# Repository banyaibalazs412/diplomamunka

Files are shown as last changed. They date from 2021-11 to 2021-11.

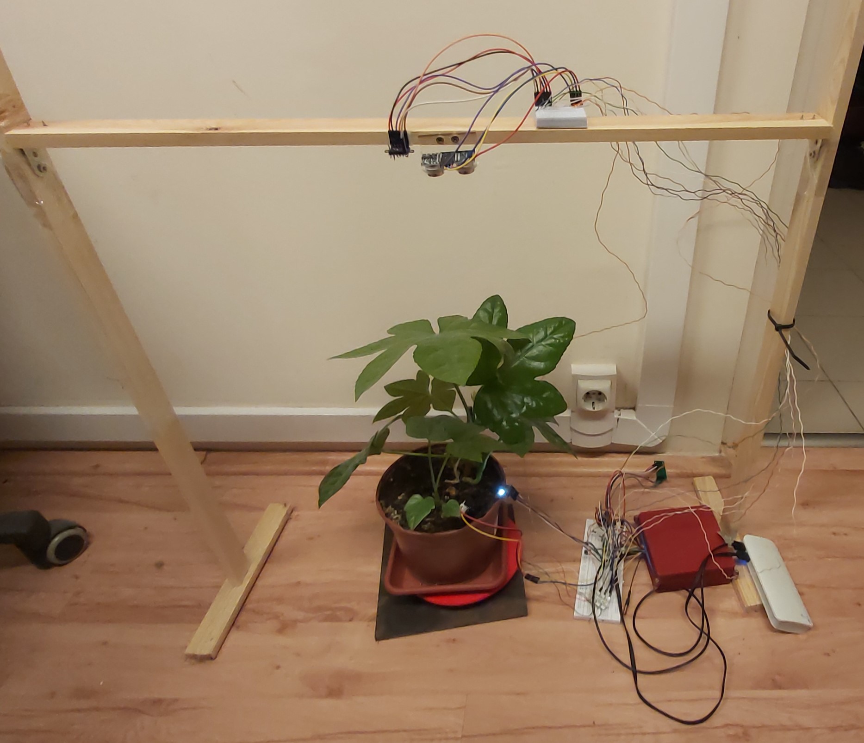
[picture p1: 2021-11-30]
abrak_egyeb/20211123_200445.jpg

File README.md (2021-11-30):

# Bányai Balázs - Diplomamunka 2021

Az állományok:

diplomamunka_frontend -> Weboldal,
ESP_code -> ESP32 mikrovezélrő Arduino kód,
greenHouseMonitoring -> ARM Cortex M alapú mikrovezérlő (STM32L452RE-P) kód,
node_api -> ExpressJs Server oldali API,
abrak_egyeb -> Minden a diplomamunkához tartozó ábra, 3D nyomtatáshoz szükséges fileok...

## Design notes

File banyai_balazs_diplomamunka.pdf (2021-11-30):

## Szegedi Tudományegyetem

## Informatikai Intézet

# DIPLOMAMUNKA

# Bányai Balázs

2021

## Szegedi Tudományegyetem Informatikai Intézet

## Növény monitorozó rendszer üvegházi alkalmazásokra

## Diplomamunka

Készítette: | Témavezető:
Bányai Balázs | Dr. Mingesz Róbert
| Zoltán
Mérnökinformatika szakos hallgató | egyetemi adjunktus

## Szeged

2021

Növény monitorozó rendszer üvegházi alkalmazásokra

Feladatkiírás

Manapság egyre nagyobb hangsúly kerül a termelési hatékonyság növelésére. Nincs ez

másképpen a növények termesztésénél sem. A hatékonyság növelésének egy módja lehet

az, hogy a növényeket és környezetüket folyamatosan megfigyeljük és adatokat gyűjtünk

be. Az adatok alapvetően jelentős információkat tartalmaznak, de a hatékonyság nagy

mértékű növelése érdekében érdemes az adatok változását valamiféle beavatkozás

eredményeként tekinteni. A fent leírtak alapján a munka célja egy olyan rendszer

kifejlesztése, ami folyamatosan monitorozza a növényeket és környezetüket üvegházi

környezetben. Az adatokat adatbázisban tárolja, és a végfelhasználónak értelmezhető

módon megjeleníti egy weboldal segítségével. Az adatok mérését és továbbítását

mikrovezérlők végzik. A mikrovezérlők az üvegházi környezet miatt vezetéknélküli

kommunikációval továbbítják az adatot. A megvalósításhoz felhasználható eszközök:

ARM Cortex M és ESP32 mikrovezérlő, adatbázis, webes keretrendszerek.

A munka során a következő alapvető funkciók megvalósítása szükséges:

- Weboldal készítése, ahol a felhasználó áttekintheti a mért adatokat.
- Felhasználói szintek kezelése (csak olvasás, paraméterek írása)
- API készítése az adatok feldolgozására
- Adatok adatbázisban való tárolása
- Növények és környezet monitorozása, adatok továbbítása
- Berendezés védelme a környezeti hatásokkal szemben.

Tartalmi összefoglaló

A téma megnevezése:

Növény monitorozó rendszer üvegházi alkalmazásokra.

A megadott feladat megfogalmazása:

A feladat egy növény monitorozó rendszer megvalósítása. A rendszer több részből áll.

Egyik része képes a növény és a környezet különböző fizikai tulajdonságait mérni. A

másik része fogadja az adatot, eltárolja, majd meg is jeleníti azt egy végfelhasználó

számára egyszerűen kezelhető weboldal segítségével.

A megoldási mód:

A feladat megoldásához szükségem volt egy teszt környezetre. Mivel a növény

magasságát vertikálisan mértem, így szükség volt egy állványra, aminek segítségével a

mérést meg tudtam valósítani. Ezen felül kellet egy növény, amin a méréseket végre

tudtam hajtani. Az jelenlegi időszakra való tekintettel egy szobanövényt választottam.

Alkalmazott eszközök, módszerek:

A rendszer magvalósításához szükségem volt két mikrovezérlőre, továbbá a méréshez

nélkülözhetetlen szenzorokra. Az adatok tárolására a MongoDB felhő alapú szolgáltatását

választottam. Az adatok feldolgozását és megjelenítését JavaScript keretrendszerek

biztosítják.

Elért eredmények:

A Feladat kiírásban szereplő követelményeket sikerült megvalósítanom. A növény

monitorozó rendszert teszteltem az általam megalkotott teszt környezetben. A feladat

során egy olyan rendszert sikerült megvalósítani, ami valós üvegházi környezetben is

megállná a helyét.

Kulcsszavak:

növény monitorozás, mikrovezérlő, VueJS, NodeJS, MongoDB, Szenzorok

Tartalomjegyzék

Bevezetés

Napjainkban egyre nagyobb hangsúlyt fektetünk arra, hogy minél hatékonyabban és

minél kevesebb pazarlással végezzük a termelést. Annak érdekében, hogy a hatékonysági

fokot növeljük, méréseket kell végezzünk, hogy legyen viszonyítási alapunk. A

diplomamunkám kifejezetten a növények üvegházi környezetben való termesztésére

összpontosít.

Két nagyobb területen is alkalmazható az általam elkészített monitorozó rendszer.

Az egyik ilyen terület a nagy mennyiségben való termesztés, ahol az elsődleges cél a

termés mennyiségének maximalizálása. Erre az alkalmazásra hasznosnak bizonyulhat

egy rendszer, ahol figyelemmel lehet követni a növény és a környezet különböző

tulajdonságait. A másik alkalmazása pedig a genetikailag módosított növények figyelése.

A közeljövőben a klíma változás hatására nagy szerepet fog kapni a genetikailag

módosított növények előállítása. Az általunk még nem ismert növények minden

változását figyelemmel szeretnénk követni annak érdekében, hogy meg tudjuk mondani

a genetikai módosítások sikerességét.

### 1. Adatbázis és szerver oldali technológiák

Az adatok tárolására a választásom a MongoDB-re esett. Az adatbázissal való

kommunikációt pedig egy NodeJS keretrendszer segítségével valósítottam meg.

Bármilyen tárolt adat lekérdezése vagy módosítása csak ezen a NodeJS

alkalmazásprogramozási felületen (későbbiekben: API) keresztül történhet meg a

rendszerben, leszámítva a direkt adatbázis műveleteket.

### 1.1 MongoDB

A MongoDB egy nyílt forráskódú dokumentum adatbázis. A dokumentum adatbázisokat

nem relációs, vagy más néven NoSQL adatbázisoknak is szokás nevezni. Ennek előnye

az, hogy nem adat táblákban kell tároljuk az adatokat egy előre megadott modell alapján,

így sokkal rugalmasabb adat struktúrákat tudunk benne letárolni. Emellett nem szükséges

az összes adatnak rendelkeznie ugyan azokkal az adat tagokkal. A MongoDB

széleskörűen elterjed a programozók körében, mivel használata nagyon egyszerű, sokkal

kevesebb megkötéssel rendelkezik, mint egy relációs adatbázis. Az adatbázis tervezési

fázisban töltött idő nagy mértékben rövidülhet. Ez főleg azért lehetséges, mert ahogy azt

már említettem, az adatbázis táblák nem egy kötött struktúrát követnek. Továbbá nem

szükséges adatbázis normalizálási lépéseket végeznünk. A NoSQL adatbázisok egyik

nagy előnye, hogy nagy mennyiségű adat tárolására is képesek drasztikus sebesség

csökkenés nélkül. Amiatt, hogy nincs szükség több tábla összefűzésére, a lekérdezéseink

is gyorsabban végre hajtódnak, mint egy relációs adatbázisban. Az én rendszeremben

nagyon sok mérési adat keletkezhet, ezért döntöttem úgy, hogy ezt az adatbázist fogom

használni. [1, 2, 3, 4]

A MongoDB a relációs adatbázisoktól eltérően dokumentumok tárolására képes.

A dokumentumok JSON alapúak, ami egy széleskörűen elterjedt adat formátum. A JSON

a JavaScript Object Notation angol kifejezés mozaik szava. Szöveges alapú,

programozási nyelv független és emberi szemmel is könnyen értelmezhető. A kis, de jól

definiált szabályai miatt könnyen kezelhető. A relációs adatbázisoktól eltérően itt nem

táblák, hanem úgynevezett collectionok (gyűjtemények) vannak, amelyek tárolják a

logikailag összefüggő dokumentumokat. [5]

### 1.2 MongoDB Atlas

A MongoDB Atlas egy felhő szolgáltatás, amit a MongoDB kínál. Az egyik nagy előnye,

hogy nincs szükség egy külön szerver gépet fent tartanunk annak érdekében, hogy a

növény monitorozó rendszerünk adatbázisa folyamatosan elérhető legyen. Ahogy az

minden felhő szolgáltatásra jellemző, ebben az esetben is egy skálázható szolgáltatást

kapunk. Csak annyi erőforrást használ az adatbázis, amennyire az adott pillanatban

szüksége van. Ha növeljük az adatok mennyiségét, vagy esetleg az adat forgalmat, akkor

a felhő szolgáltató számunkra nem észrevehető módon bővíti a felhasználható

erőforrásokat. Az Atlas folyamatos backup mentéseket hajt végre időközönként annak

érdekében, hogy az adataink ne vesszenek el valamiféle meghibásodás következtében. Az

adatbázis elérése szempontjából is előnyös lehet számunkra a felhő szolgáltatás, mivel a

világ teljes területén biztosítanak szervert számunkra. A MongoDB Atlas önmagában

nem nyújt felhő szolgáltatást, de a legnagyobb felhő szolgáltató cégekkel együtt működve

több szolgáltatón keresztül is lehetséges a szolgáltatás igénybevétele. Igénybe vehetjük

az Amazon Web Service (AWS), Microsoft Azure vagy akár a Google Cloud Platform

szolgáltatásait is. Sőt, lehetőségünk van akár több szolgáltatást is használni egyszerre. A

diplomamunkámban az AWS szolgáltatás választottam, mivel régionként különböző

árazással rendelkeznek és esetemben bizonyos korlátokig ez az opció ingyenesen

használható. A rendszer bővülésével, mind az adat mennyiség, mind a területi eloszlást

figyelembe véve érdemes lehet megvizsgálni, hogy melyik szolgáltatás a legelőnyösebb

számunkra. A szolgáltatók sok esetben más mennyiségek szerint készítik az árszabásukat.

Valahol az adat mennyisége, valahol a szerverrel való kommunikációk számát mérik, de

további mérőszámokat is alkalmaznak. A MongoDB Atlas online kezelőfelületén

lehetőségünk van figyelni, hogy az adatbázisunkhoz az elmúlt időben hányan

csatlakoztak és mekkora adatforgalmat generáltak. Az adatforgalom kijelzésénél külön

választva nézhetjük az írt és olvasott adat mennyiségeket is. [6, 7]

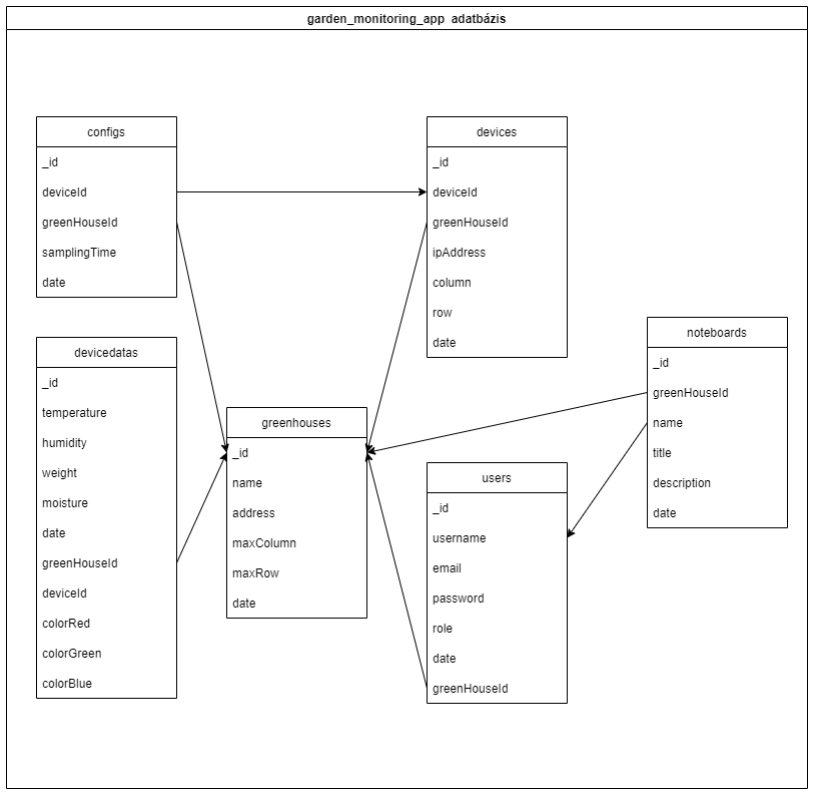
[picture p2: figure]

1.2 1. ábra Adatbázis felépítése

### 1.3 NodeJS

A NodeJS egy JavaScript runtime ami alapvetően aszinkron működésre lett tervezve

szerver oldalon. Olyan alkalmazásoknál, ahol szerver oldalon nem szükséges nagy

számításokat végezni, előszeretettel használják egyszerűsége és gyorsasága miatt. A

fejlesztőknek nem kell foglalkozniuk a szálkezeléssel, mivel a kérések nem blokkolják

egymást. A másik nagy előnye, hogy egyszerűen összekapcsolható MongoDB

adatbázisokkal. Az egyik legnagyobb hátránya, hogy relációs adatbázisokkal viszont

nehezebben összekapcsolható, mivel a kapcsolódáshoz tartozó függvény könyvtárak

fejlesztése lassabban halad, mivel a felhasználói igény sem túl nagy ezeknek a

fejlesztésére. A NodeJS által használható függvénycsomagok telepítése egy úgynevezett

package manager-en keresztül történik, aminek a neve Node Package Manager (npm). A

package managerre úgy is tekinthetünk, mint egy nyílt közösségi függvénycsomag

tárhely. [8, 9]

### 1.4 Express JS

Az Express JS egy ingyenes, nyílt forráskódú NodeJS keretrendszer, aminek segítségével

gyorsan és egyszerűen tudunk JavaScript alapú szerver oldali alkalmazásokat fejleszteni.

A növény monitorozó rendszer esetében ezt a keretrendszert használtam arra, hogy

készítsek egy olyan szerver oldali JavaScript API-t, ami HTTP protokollon keresztül

hívható, és feladata az adatbázis és a weboldal/mikrovezérlő közti kommunikáció

megteremtése. Mivel az adatokat kis mértékben módosítjuk, és vannak olyan végpontok,

amik nem csak adatbázisban való módosításra hivatottak így szükségünk volt egy köztes

rétegre és ez a köztes réteg az Express API. [10, 11]

### 1.5 Szerver oldali Express alkalmazás létrehozása

Első lépésként az eszközünkre telepítenünk kell a már előbbiekben említett NPM package

manager-t, majd a NodeJS-t. A projekt létrehozását könnyen meg tehetjük Windows

operációs rendszeren egy Windows Power Shell vagy egy Command promt segítségével.

Linux vagy MacOS operációs rendszernél pedig egy terminál segítségével. Az npm init

parancs kiadásával létrehozzuk a projektünk alap tulajdonságait leíró package.json file-t.

A parancs kiadása után meg tudunk adni olyan tulajdonságokat, hogy mi a projekt neve,

ki a szerző, mi a készülendő projekt verzió száma, rövid leírása, belépési pontja és még

sok más a projektet leíró tulajdonságot.

A package.json file a későbbiekben nem csak a projekt alapvető szöveges

tulajdonságait fogja leírni, de itt fogja tárolni a projektben használt függőségek listáját is.

Ha a projektet meg szeretnénk osztani másokkal, esetleg valamilyen verziókezelőt

használunk, akkor fontos, hogy ezt a file-t mindenképpen mellékeljük. Bevett szokás,

hogy a node_modules könyvtárat, ahol a valós függvénycsomagok tarolódnak nem

osztjuk meg, mivel sok kis méretű állományt tartalmaznak, amely elérhető az NPM

package manager segítségével, így feleslegesen terhelnénk a tárhelyet. Emellett a

függőségek listájában a szükséges csomagok verziószáma is el van tárolva, ezzel

biztosítva azt, hogy másik eszközön való üzembe helyezés során ne lépjenek fel

verziószám különbség által keletkező problémák. Másik eszközön való beüzemeléshez

elegendő belépnünk abba a könyvtárba, ahol a package.json file található és

parancssorból ki kell adjuk az npm install parancsot.

Az Express JS keretrendszer telepítése sem különbözik a többi függvénycsomag

telepítésétől. A csomagok telepítése a következő paranccsal történik npm install

<függvénycsomag neve><@verziószám>. A „@” jel és a verzió szám megadása

opcionális. Abban az esetben, ha ezt nem adjuk meg, akkor a legfrisseb elérhető verzió

kerül telepítése. Ezen felül van lehetőségünk a csomag telepítésére lokálisan a projekthez

és globális a számítógépünkre. Alapvetően a projekthez fogja telepíteni, de a -g kapcsoló

megadásával az eszközünkre is tudjuk telepíteni. Ez akkor lehet előnyös, ha több

projekten is dolgozunk, ami ugyan azokat a csomagokat használják és ugyan azon

verziószámmal. Ezek alapján az Express JS telepítése a projektünkhöz az npm install

express paranccsal történik.

### 2. A rendszerhez tartozó Express API

Elsőnek létre kell hozzuk az package.json-ben megadott belépési pontot, ami esetemben

az index.js file. Mielőtt elkezdnénk a fejlesztést érdemes hozzá adnunk a projektünkhöz

egy csomagot, aminek az a neve, hogy nodemon. Ez a csomag fejlesztés alatt segít majd

minket. A nodemon lényege az, hogy nem kell minden változtatásnál újra indítanunk az

alkalmazást, mert minden file változás esetén ő ezt automatikusan elvégzi, ami nagyban

gyorsítja a fejlesztési folyamatot.

Az express keretrendszer használatához jeleznünk kell, hogy használni fogjuk az

express csomagot. A használathoz a require() függvényt kell használnunk, a dolgunk csak

annyi, hogy a függvény paraméterében String formában meg kell adjuk a használni kívánt

csomag nevét. Az express esetén szükségünk van egy példány létrehozására is, amit a

későbbiekben használni fogunk.

2. 1. ábra Express példány létrehozása

Ez után tudjuk használni az app példány függvényeit. Ahhoz, hogy elérjük az API-t be

kell állítsunk egy portot, amit figyel és itt fogja várni a HTTP kéréseket. Ezt az

app.listen() függvény segítségével tehetjük meg. A függvény egy Number típusú

paramétert vár, ami az általunk megadott portot fogja jelenteni. Esetemben ez a 3000-es port lesz, de bármilyen nyitott port megadása lehetséges. Ezután az alkalmazásunkat az

npm start parancs kiadásával tudjuk futtatni a nodemon miatt, és futása alatt végig figyeli

a 3000-es porton érkező kéréseket.

### 2.1 Mongoose

Miután már van egy futó alkalmazásunk, létre kell hozzuk a kapcsolatot az

adatbázisunkkal. A kapcsolat létrehozáshoz és minden adatbázis művelethez a mongoose

csomagot használtam, amely kifejezetten a MongoDB és a NodeJS alkalmazások

összekötésére lett kitalálva. Használata nagyon egyszerű és a csomag nagyon jól

dokumentált.

Használatához hasonló módon a require() függvényt kell használnunk. Az

adatbázishoz való csatlakozáshoz a mongoose.connect() függvényt tudjuk használni,

amelynek az első paramétere az adatbázis elérési útja. Ezt könnyen meg tudjuk nézni a

MongoDB Atlas kezelőfelületén. Lehetőségünk van kiválasztani, hogy milyen

programozási nyelven készítjük az alkalmazást, és miután ezt meg tettük, meg kapjuk az

elérési utat, sőt még egy rövid példa kódot is a beüzemeléséhez. A mongoose.connect()

függvénynek van egy második opcionális paramétere amellyel egyéb adatbázis

kapcsolathoz köthető beállításokat lehet megadni. Ezen opciók listája megtalálható a

mongoose dokumentációjában. A monitorozó rendszerben nem használok az adatbázis

elérési úton kívül semmilyen egyéb beállítást.

A mongoose segítségével létre tudunk hozni adat sémákat, amelyben meg tudjuk

adni, hogy a dokumentumok milyen attribútumokkal fognak rendelkezni. Az

attribútumokhoz meg tudjuk adni a nevüket, hogy milyen típusúak (csak JavaScript

beépített típusok), hogy kötelezően meg kell-e adjuk és ha szükséges, akkor egy alap

értéket is. Továbbá a séma második paramétereként egy verzió kulcs is megadható, de én

ezt az opciót nem használom. Az így definiált sémából létre tudunk hozni egy úgynevezett

mongoose modelt. A mongoose model létrehozásához szükségünk van egy collection

névre és az előbbiekben leírt mongoose sémára.

### 2.2 Jogosultsági körök

Az egész monitorozó rendszerben három féle jogosultsági kört különböztetünk meg. Ezek

szükség esetén a későbbiekben könnyen bővíthetőek. Az egyik jogosultsági kör a „User”, aki egy sima felhasználó. A User képes lekérdezni monitorozási adatot a hozzá rendelt

üvegházból, de beavatkozni sehova se tud. A második jogosultsági kör az „Admin”, aki

egy üvegház vezetőjének felel meg. Lehetősége van az üvegházhoz tartozó monitorozási

adatok lekérdezésére. Ezen felül kezdeményezhet egy azonnali mérést az üvegházhoz

rendelt mikrovezérlőn. Továbbá lehetősége van az üvegház adatainak módosításához,

vehet fel új eszközöket a saját üvegházhoz, módosíthatja a meglévő eszközök

konfigurációját és kezelheti az üvegházhoz rendelt felhasználókat. Az utolsó jogosultsági

kör a „SuperAdmin”. Valójában ez egy rendszer üzemeltető jogkör. A monitorozási

adatokhoz nem fér hozzá. Szerepe, hogy új üvegházakat vegyen fel és az üvegházakhoz

Adminokat rendeljen.

### 2.3 JWT

A JWT az angol JSON Web Token kifejezésből ered. Szerepe a biztonság növelése,

emellett használható a felhasználók azonosítására is. Az express alkalmazásban a

jsonwebtoken csomag segítségével tudjuk használni. A bejelentkezési fázisnál az

alkalmazás generál egy JWT tokent, amely bizonyos végpontok hívásánál

nélkülözhetetlen. Ha ezeket a végpontokat JWT nélkül szeretnénk hívni, akkor hiba

üzenetet kapunk válaszul a kérésünkre. A JWT generáláshoz HS256 titkosítási

algoritmust használ, ami egy szimmetrikus titkosítás. A kulcs generáláshoz szükségünk

van egy úgynevezett secretre. Az alkalmazásomban erre létre hoztam egy külön config.js

file-t, amiben ezt könnyedén tudjuk változtatni.

2.3 1. ábra JWT token generálása

Az ábrán látszik, hogy a jsonwebtoken csomag sign() függvény segítségével tudunk

tokent generálni. Három paramétert vár, az első a felhasználó azonosítója, a második az előbbiekben említett secret és a harmadik paraméterben több beállítás is megadható. Én

egyedül a lejárati időt adtam meg, ami jelenleg 24 óra. A token lejáratával újból be kell

jelentkeznünk és kapunk egy új tokent, ami további 24 óráig érvényes lesz.

Ahogy azt írtam a biztonságon kívül lehetőségünk van a token által a felhasználók

azonosítására is. Az authJwt.js file úgy működik, mint egy köztes réteg. Azon

végpontoknál, ahol szükséges a JWT token, meg tudjuk adni, hogy milyen jogosultsági

szinttel rendelkező felhasználók férnek hozzá az adott végponthoz. A tokent a HTTP

kérés header részében küldjük el. Az említett köztes réteg pedig megvizsgálja az

érvényességét a jwt.verify() függvény segítségével, aminek két paramétere van, az első a

token, a második pedig a generálásánál alkalmazott secret. Ha a generálásnál és az

ellenőrzésnél megadott secret nem egyezik meg, akkor nem tudjuk validálni a tokent. Ha

valamilyen felhasználó szerepkör is tartozik a végponthoz, akkor annak meglétét is

ellenőrzi. Az ellenőrzés úgy történik, hogy a tokenből meg tudjuk állapítani a felhasználói

azonosítót. Ha ez sikeresen megtörtént, akkor az adatbázisból lekérdezzük az adott

felhasználót, majd, ha ez megtörtént, akkor megvizsgáljuk, hogy milyen jogosultsági

szinttel rendelkezik. Ha bármelyik lépésnél hibát észlelünk, akkor nem engedjük tovább

a végpont hívást és szöveges hiba üzenetet küldünk válaszként. [13, 14]

### 2.4 User model és végpontok

A user végpontok a felhasználóval kapcsolatos műveletekért felelősek. A user végpont

hívása a következő útvonalon lehetségesek „<szerver címe>/api/user”. A user model

felépítése a következő:

- username (String, required)
- email (String)
- password (String, required)
- role (String, default: ’User’)
- greenHouseId (String)
- date (Date, default: Date.now)

A fent említett modelben a required mezőket kötelező megadnunk, míg a default

kulcsszóval rendelkező mezőknél, ha nem adunk meg nekik értéket, akkor ezt

alapértelmezetten meg kapják az adatbázis dokumentum létrehozásánál. A Date.now egy

JavaScript függvény, aminek a segítségével az adatbázisba való beszúrás időpontját

tárolhatjuk.

A „/api/user/” végpont HTTP GET metódus hívására csak bejelentkezett

felhasználók jogosultak. Ezen felül vagy Admin vagy SuperAdmin jogosultsági körrel rendelkező felhasználóknak engedélyezett. Ha a lekérdezést egy Admin jogosultsági

körrel rendelkező felhasználó hívja meg, akkor azokat a felhasználókat kapja válaszul,

akik ugyan azzal a greenHouseId-val rendelkeznek. Abban az esetben, ha egy

SuperAdmin hívja meg, akkor az összes felhasználót meg kapja válaszul.

A „/api/user/userByToken” végpont HTTP GET metódus hívására csak

bejelentkezett felhasználók jogosultak. Ez a végpont azt a célt szolgálja, hogy

lekérdezzük a weboldalon már bejelentkezett felhasználó felhasználónevét, email címét

és a jogosultságát. Abban az esetben, ha nem található felhasználó az adatbázisban a kérés

headerjében szereplő token alapján, hibát küldünk vissza a válaszban.

A „/api/user/login” végpont HTTP POST metódus hívás a felhasználó

bejelentkezéséért felel. Mivel a bejelentkezésnél még nincs tokenünk, így nincs szükség

tokenre a bejelentkezéshez. A HTTP kérés törzsében várja a username és a password

adattagokat. Ha a username nem található az adatbázisban, akkor hiba üzenetet küldünk,

hogy a felhasználó nem létezik. Ha a felhasználót megtaláltuk, de nincs hozzá rendelve

üvegház, akkor szintén hiba üzenetet küldünk, mivel csak olyan felhasználókat

szeretnénk beengedni a rendszerbe, akik ezzel rendelkeznek, kivéve, ha a jogosultsági

köre SuperAdmin. Ha eddig eljutott az adatok feldolgozása, akkor megvizsgáljuk, hogy

a jelszó meg egyezik-e az adatbázisban lévővel. Az adatbázisban a jelszót titkosítva

tároljuk. Abban az esetben, ha minden sikeres volt legeneráljuk a JWT tokent és

válaszként visszaküldjük a felhasználó összes adatát és a tokent.

A „/api/user/register” végpont HTTP POST metódus hívására történik meg a

felhasználó regisztrálása. Mivel a regisztrációs adatoknál nem csak egyezőséget kell

vizsgáljunk, ezért használok egy express-validator NPM csomagot. A validálásnál olyan

kritériumokat szabtam meg, hogy a jelszó hossza legalább öt karakter kell legyen, az

emailnek meg kell feleljen az email szabványokan és a felhasználónév nem lehet üres.

Ezen felül egyik sem tartalmazhat speciális karaktereket és a felesleges whitespaceket az

elején és végén is levágom. Minden egyes kritériumra hiba üzenetet küldünk tömb

formájában, hogy ne csak az első hibát lássa a felhasználó abban az esetben, ha több

kritériumban is hibás adatot adott meg. A server oldali validálás nagyon fontos, mivel az

informatikában jártasabb emberek nem csak az alkalmazáshoz készített weboldalon keresztül tudnak API végpont hívásokat intézni. Így abban az esetben is csak helyes

adatokra végzünk adatbázis műveletet, ha valaki direkt végpont hívást alkalmaz. Ha

sikerült helyes adatokat megadni a felhasználónak, akkor a jelszavát az adatbázisba írás

előtt titkosítjuk. A titkosítás a bcrypt NPM csomag segítségével történik. Egy több körös titkosítás használ, esetemben a körök számát egy saltRounds nevű konstansban tárolom,

aminek az értéke 10.

A módosításhoz és törléshez HTTP PUT és DELETE metódusokat használom a

„/api/user” végponton. Mindkét végpont hívás esetén Admin vagy SuperAdmin

jogosultságra vagy szükségünk. Emellett Admin esetében csak azon felhasználókra

hívhatja meg ezeket a végpontokat, akik ugyan ahhoz az üvegházhoz vannak rendelve. A

törléshez a HTTP üzenet törzsében csak egy id attribútumok kell elküldenünk. Abban az

esetben, ha ezt meg találja az adatbázisban, akkor azt ki törli. A módosítás egy kicsit

másabb. Itt is kötelező az id megadása, de mellette el kell küldjük azokat az

attribútumokat is, amiket változtatni szeretnénk.

### 2.5 GreenHouse modell és végpontok

A greenHouse végpontok az üvegház műveletekért felelnek. A végpontok hívása a

következő útvonalon lehetséges „<szerver címe>/api/greenHouses”. A GreenHouse

model a következőképpen néz ki:

- name (String, required)
- address (String)
- maxColumn (Number, required)
- maxRow (Number, required)
- date (Date, default: Date.now)

Az maxColumn és a maxRow az üvegház mátrix szerű felosztására szolgál. A

későbbiekben az üvegházak adott oszlopaihoz és soraihoz eszközöket fogunk rendelni. A

felosztás segíti a tájékozódást és abban az esetben, ha nem rendelkezünk elég eszközzel,

akkor lehetőségünk van egy redukált monitorozásra, ahol egy mátrix cellát tekinthetünk

egységesnek. Megfelelő méretű cellák esetén nagyon hasonló körülményeknek vannak

kitéve a növényeink, ezért valószínűleg hasonló eredményt kapnánk egy cellán belül lévő

eszközök esetén. Ez lehet egy költség csökkentési szempont is, mivel a pontosság csak

kis mértékben romlana, de a költségek jelentős mértékben csökkennének. Ezt a felvetés

a későbbiekben érdemes lehet tesztelni éles nagyipari környezetben.

Az üvegházak listázásához, létrehozásához, törléséhez és módosításához a

„/api/greenHouses” végpontok hívhatok HTPP GET/POST/PUT/DELETE metódusok

használatával. Mindegyik metódus esetén szükséges a bejelentkezés és a SuperAdmin jogosultsági szint. A GET hívás esetén minden létező üvegházat megkapunk válaszul. A

POST hívás esetén a modelben szereplő összes kötelező attribútumot tartalmaznia kell a

kérés törzsének, különben hibát kapunk. A PUT hívás esetén az üvegház _id

attribútumnak kell szerepeljen, ami az adatbázis által létrehozott dokumentum

azonosítója. Ezen felül el kell küldjük az összes módosítani kívánt adat tagot. A DELETE

hívás esetén csak egy id-t kell küldjünk.

Lehetőségünk van egy adott üvegházban elérhető maximum oszlop és sorszám

lekérdezésére is, amit a weboldal fog használni arra a célra, hogy kiválasszunk egy

üvegház cellát. Ezt a „/api/greenHouses/maxColAndRow” végponton érhetünk el. Az

eléréséhez nem szükséges jogosultság, csak bejelentkezés. Nem vár semmilyen adatot,

mivel a felhasználó tokenen keresztül tudja az adott üvegházat. A lekérdezésünk válaszul

a maxColumn, maxRow és a deviceNumber adatot küldi vissza. A deviceNumber az

üvegházhoz rendelt összes eszköz száma.

A greenHouse végpontok között szerepel egy olyan végpont, ami az üvegházakat

kérdezi le, de csak egy redukált formában. Visszatérése egy tömb, amiben csak az id és a

name van. Ez biztonsági és adatforgalmi szereppel is jelentkezik. Minden végpont esetén

törekedtem arra, hogy csak azokat az adatokat adják vissza, ami az adott funkcióhoz kell.

Ezt a „/api/greenHouses/getGreenHouseListForVue” végponton lehet elérni SuperAdmin

jogosultsági szinttel.

### 2.6 NoteBoard model és végpontok

A weboldalon megtalálható egy üzenőfal, melynek az a szerepe, hogy a növények

gondozásában résztvevő emberek információkat oszthassanak meg egymással. Fontos

lehet, hogy legyen egy közös felület, amely csak egy adott üvegházhoz tartozik így fontos

információkat tudnak egymással megosztani a gondozók. A NoteBoard model a

következőkből áll:

- name (String, required)
- greenHouseId (String)
- title (String, required)
- description (String, required)
- date (Date, default: Date.now)

A name mező tárolja a felhasználó nevét, a title a bejegyzés címét és a description a

bejegyzés lényegi részét.

A bejegyzéseket nem lehet módosítani vagy törölni, hogy az üzenet folyam

folyamatos legyen, és az üvegház felelőse részletesen lássa az eseményeket. A

„/api/noteBoard” GET metódus hívásra dátum szerint csökkenő sorrendben meg kapjuk

az összes bejegyzést. A végpont eléréséhez a felhasználó bejelentkezése szükséges, mivel

a token segítségével állapítjuk meg a felhasználóhoz tartozó üvegházat és csak a

felhasználóhoz tartozó üvegházhoz rendelt bejegyzéseket szeretnénk megjeleníteni.

Ugyan erre a végpontra hívott POST metódus segítségével új bejegyzést hozhatunk létre.

A kérés törzsében szerepelnie kell a title és a description tagoknak.

### 2.7 Config model és végpontok

A Config végpontnak az a szerep, hogy az eszközök bizonyos beállításait futás közben

dinamikusan tudjuk állítani. Jelenleg ennek a mintavételezési időben van szerepe. Meg

tudjuk adni, hogy az eszközök egyenként milyen sűrűn küldjenek mérési adatokat. A

config model a következő:

- deviceId (Number, required)
- greenHouseId (String, required)
- samplingTime (Number, default: 10)
- date (Date, default: Date.now)

A samplingTime a mintavételetzési időközt jelenti percben megadva.

A mikrovezérlőhöz tartozó konfiguráció lekérdezése a „/api/config” végpont GET

lekérdezéssel lehetséges. Lekérdezési paraméterben meg kell adjuk a deviceId-t.

A weboldal segítségével ezt módosíthatjuk is. Ezt az előző végpont POST

hívásával tehetjük meg. A hívásban ugyan azokat az adatokat kell megadjuk, csak a

lekérdezés törzsében. Ha sikerült megtalálnunk ezt a konfigurációs ad azatbázisban,

akkor lekérdezzük a hozzá tartozó eszköz IP címét is, amit szintén tárolunk az

adatbázisban. Annak érdekében, hogy az eszköz frissítse a mintavételezési időközt,

valahogy tájékoztatnunk kell a változásról. Hogy ezt meg tudjam valósítani az eszközön

fut egy HTTP szerver, ami folyamatosan várja a hívásokat. Ha az eszköz „/config”

útvonalára intézünk GET lekérést, akkor ezt fogadja és egy 200-as státusz kódú válasszal

tér vissza. Ezzel jeleztük a változást és a többi teendőt az eszköz végzi.

Mivel az eszközöknél nem használunk tokeneket, így nem tudjuk a tokenből

meghatározni a greenHouseId-t. Egy külön „/api/config/deviceGetData” végpontot

kellett létrehozni annak érdekében, hogy a mikrovezérlő is le tudja kérdezni a hozzá

tartozó konfigurációt. Ez annyival másabb, hogy itt lekérdezési paraméterben meg kell

adjuk a greenHouseId-t is a deviceId-n kívül.

2.8 Device model és végpontok, DeviceData model.

A Device végpontok egyszerre szolgálnak az eszközök nyilvántartására és az általuk

küldött mérési adatok kezelésére. A Device model a következő:

- deviceId (Number, required)
- greenHouseId (String, required)
- ipAddress (String, required)
- column (Number, required)
- row (Number, required)
- date (Date, default: Date.now)

Az ipAddress a konfiguráció változásánál értesítendő út miatt szükséges. A column és a

row az eszköz celláját azonosítja az üvegházban. A DeviceData model a következő:

- deviceId (Number)
- greenHouseId (String)
- laserDistance (Number)
- sonicDistance (Number)
- temperature (Number)
- humidity (Number)
- weight (Number)
- moisture (Number)
- colorRed (Number)
- colorGreen (Number)
- colorBlue (Number)
- date (Date, default: Date.now)

Ezek az adatok arra szolgálnak, hogy az eszközök által érzékelt mennyiségeket el

tároljuk, hogy lássuk mi történik a növénnyel és környezetével az idő teltével.

Lehetőségünk van lekérdezni a felhasználó üvegházához tartozó eszközöket a

„/api/device” végponton keresztül GET lekérdezéssel. Mivel az üvegház lekérdezése

tokenen keresztül történik, így szükségünk van a bejelentkezése, de további jogosultság

nem szükséges. Ugyan erre a végpontra küldött POST kérés esetén lehetőségünk van

eszköz létrehozására és módosítására, de el kell küldjük a model kötelező mezőit a kérés

törzsében. Ez a végpont annyival másabb a többi POST hívástól, hogy sikeres eszköz

mentés esetén létre hozunk egy Config dokumentumot is az adat táblában az alap

samplingTime értékkel. A DELETE metódus hívásra az eszköz törölhető a kérés

törzsében megadott id alapján.

A „/api/device/deviceList” GET kérés esetén visszakapjuk az eszközök egy

redukált listáját a megadott cellában (oszlop és sor páros). A válasz tartalmazza a

felhasználó üvegházához tartozó összes eszköz deviceId-ját és az adatbázis által

létrehozott dokumentum _id-t, amik az adott oszlopban és sorban vannak. Az oszlop és

sor adatok a lekérdezés paraméterében kell megadjuk.

Mivel az adatokat erősen kötődnek az eszközökhöz, ezért egy végpont csoportban

kezeltem az eszközöket és a hozzájuk tartozó adatokat. Az adatok lekérdezésére a

„/api/device/deviceData” végpont lett létrehozva. Mindössze annyi dolgunk van, hogy a

lekérdezés paraméterének át adjuk az eszköz dokumentum _id-jét. Abban az esetben, ha

megadjuk paraméterként a date tagot is, akkor az adott napra vonatkozó mérési adatokat

kapjuk vissza. Ennek a weboldalon lesz nagy szerepe, mivel nem minden esetben

szeretnénk az összes mérési adatot látni. Ez akkor lesz előnyös, ha már huzamosabb ideje

mér az eszközünk, de mi csak bizonyos napok adataira vagyunk kíváncsiak. Ugyan ebből

a megfontolásból, az összes mérési adatot dátum szerint csökkenő sorrendben kapjuk

meg.

A weboldalon lesz lehetőségünk arra, hogy azonnali mérést kezdeményezzünk

egy eszközzel. Ehhez valahogyan jeleznünk kell a mikrovezérlőnek. Ismét azt a módszert

választottam, hogy az eszközön lévő HTTP szervernek küldünk egy üzenetet, hogy

kezdje meg a mérést. Ezt a „/api/device/startMeasurment” végpont hívásával tehetjük

meg. Paraméterként a deviceId-t várja. Meghívása után elküldi az eszköz IP címére a

kérést.

A végpontok nagy része eddig a weboldallal volt kapcsolatba hozható. A

„/api/device/measuredData” végpont viszont az eszközök számára van fenntartva. Az

eszköz elküldi az összes DeviceData model által leírt adatot és ezt módosítás nélkül

elmentjük az adatbázisunkba.

### 3. Monitorozó rendszer kezelő weboldal

Az általam megalkotott weboldal Vue.Js keretrendszer segítségével íródott. Manapság az

egyik legelterjedtebb JavaScript alapú keretrendszer. Tökéletesen alkalmas egyszerű

weboldalak létrehozására, de lehetőségünk van komplexebb igényeket is megvalósítani

segítségével. Mivel komponens alapú, így lehetőségünk vagy egy már meglévő

komponens használatára több helyen is. Ez hasznos lehet olyan esetekben, mikor nagyon

hasonló elemeket szeretnénk létrehozni. Ennek segítségével elkerülhető a kód duplikáció.

Sokkal igényesebb és átláthatóbb kódot adhatunk ki a kezeink közül, ha kihasználjuk a

keretrendszer nyújtotta lehetőségeket. A kinézet kialakításában segítségemre volt a

bootstrap-vue CSS könyvtár. Segítségével egyszerűen egységes kinézetre hozhatjuk az

egész weboldalt. [15, 16]

A vue kiterjesztésű fileok két fő részből tevődnek össze. Az egyik a template rész,

ami többnyire HTML kódot tartalmaznak. Lehetőségünk van „közbe ékelni” JavaScript

elemeket is. Amikor a felhasználó lekérdezi az adott oldalt, akkor a template részben lévő

JavaScript kód HTML kódra fordul és a felhasználóhoz már csak egy kész HTML kódot

juttatunk el. A másik fő része a script rész. Itt tudunk létrehozni és módosítani adat

tagokat, amit a későbbiekben majd a template részben használni tudunk. Továbbá

lehetőségünk van események bekövetkezésére eljárásokat végre hajtani. Ez hasznos olyan

esetekben, amikor például kattintásra eseményre szeretnénk műveletet végrehajtani, de

nem szeretnénk gombokat használni ennek megvalósításra.

### 3.1 Belépési pont

A weboldal belépési pontja az src mappában található main.js. Az állomány elején

lehetőségünk van jelezni, hogy milyen csomagokat szeretnénk használni az

alkalmazásunkban, ezt az import kulcsszóval tehetjük meg. A projekt létrehozásakor már

legenerált importálásokon felül saját magam is importáltam pár hasznos csomagot. Az

egyik ilyen csomag a már említett bootstrap-vue, amely a weboldalon megjelenő elemek

kinézetéért és a reszponzivitásért felel. A következő ilyen csomag a vue-select, amely a

lenyíló bemeneti mezők kezelését könnyíti meg. Ezen felül nagyon hasznos csomag az

axios. Abban játszik szerepet, hogy könnyedén meg tudjuk hívni az Express API

végpontokat és az általa visszaadott adatot. Legvégül egy vuejs-noty csomagot használtam, amivel letisztult értesítéseket küldhetünk a felhasználók számára. Jelenleg az

API végpont hívások sikerességét és sikertelenségét jelzi.

A csomagok importálása után végre kell hajtsunk pár beállítást annak érdekében,

hogy egyszerűen tudjuk kezelni az API végpontokat. Be kell állítanunk az API elérési

útját, amihez majd a későbbiekben hozzá fűzünk további elérési utakat.

Az alkalmazásban használok LocalStorage-t, ami adatok tárolását teszi lehetővé

az oldalt látogató felhasználók böngészőjében. Azért lesz erre szükségünk, mert a

felhasználó azonosítására használt tokent le tudjuk itt tárolni és nem szükséges újra

bejelentkeznünk az oldalra, ha bezártuk az adott böngésző oldalt. Abban az esetben, ha

belépünk a main.js belépési ponton keresztül és létezik a LocalStorage-ban token, akkor

ezt hozzá adjuk az axios által intézett HTTP lekérdezések fejléc mezőjébe, amit majd az

API képes lesz értelmezni és így azonosítani a felhasználót. Ha végeztünk ezekkel a

lépésekkel, akkor betöltjük az App.vue állományt.

### 3.2 Vue store

A vue store lehetőséget ad számunkra, hogy szerver oldalon tároljunk adatokat, amely a

teljes alkalmazásban elérhető. Minden egyes felhasználó által megnyitott böngésző

oldalhoz létrehoz egy külön store-t, amelyben az adatok csak a megnyitott lapon lesznek

elérhetőek. A storeban lévő adatokat módosíthatjuk és lekérdezhetjük. A weboldalamon

egyetlen store-t használok, ahol a felhasználó adatait tárolom. Ez a store mappában érhető

el a user.js fileban. Az itt található adatok a következőek:

- username (felhasználónév)
- email (felhasználó email címe)
- token (felhasználó azonosítására szolgáló token)
- role (felhasználó jogosultsági szintje)
- greenHouseId (felhasználóhoz rendelt üvegház azonosítója)
- isLoggedIn (a felhasználó be van-e jelentkezve)

Két nagyobb művelet található meg az adatok mellett. Az egyik az initUser amelynek a

szerepe, hogy bejelentkezéskor, vagy az oldal megnyitásakor betöltse az adatokat a

storeba | a | token | segítségével. | A | függvény | meghívásakor | meghívjuk | a

„/api/user/userByToken” végpontot, ami válaszul pontosan ezeket az adatokat fogja

visszaadni és betölti a storeba. Ha a művelet sikertelen, akkor egy hiba értesítést kapunk.

A másik nagyobb művelet a logout. Amikor a felhasználó kijelentkezik, akkor szeretnénk,

ha minden store-ban lévő adata törlődne. A művelet az összes fentebb említett adatot null

értékre állítja.

### 3.3 App.vue és a router

Az App.vue renderelését a main.js végzi el, ami az alkalmazás belépési pontja. Az

App.vue létrehozásakor a fentebb említett initUser store művelet fut le, aminek az a

szerepe, hogy ha a felhasználó már bejelentkezett és a tokene érvényes, akkor töltsük ezt

be a storeba és ne keljen újra bejelentkeztetni.

Az App.vue-ban megtalálható egy router-view componens ami azért felel, hogy

különböző URL-re különböző oldalakat töltsünk be. Azt, hogy milyen URL-re melyik

oldalt kell betölteni, azt a router mappában található index.js fogja eldönteni.

A routes konstants tárolja azokat az utakat, ahova el tudjuk navigálni a

felhasználót. A routes egy tömb, ami objektumokat tárol. Minden objektum egy

útvonalért felel. Az objektum path tagjában tudjuk meghatározni, hogy milyen útra lépjen

életbe. A name tag szolgál arra, hogy a projektünkön belül tudjuk navigálni a felhasználót.

Ezt meg tehetnénk úgy is, hogy egy sima anchor elemmel át irányítjuk egy másik URL-

re, de ebben az esetben az oldal újra töltődik. Ezzel elveszítené az oldalunk a Single Page

Application szerepét, amit mi nem szeretnénk. Az átirányításoknál a name segítségével

úgy tudunk át navigálni egy másik oldalra, hogy nem kell újra töltenünk az oldalt. A

component tag segítségével tudjuk megadni azt, hogy milyen componenst töltsön be az

oldalunk egy adott útvonalra. A meta részben az úthoz tartozó speciális tulajdonságokat

írtam le. Az itt szereplő tagok fogják meghatározni, hogy egy felhasználó beléphet-e az

adott oldalra, vagy sem.

Az előbbiekben említett meta taget meg kell vizsgáljuk minden egyes útvonalra

való belépéskor. Ezt a router.beforeEach függvénnyel tehetjük meg. Ez a függvény

minden egyes router esemény előtt meghívódik és meg kapjuk az is, hogy milyen

útvonalról milyen útvonalra szeretnénk lépni. A weboldalt egyik szolgáltatását sem lehet

igénybe venni mindaddig, amíg nem jelentkezünk be. Kivétel ez alól a bejelentkezés és a

regisztráció. Minden más esetben, ha bejelentkezés nélkül szeretnénk meglátogatni egy

oldalt, akkor át irányítjuk a bejelentkezés oldalra, hogy kötelezzük a belépésre. Továbbá

ebben a függvényben vizsgáljuk meg azt is, hogy a felhasználó jogosult-e az adott oldal

látogatására, ha nem, akkor szintén a bejelentkezési oldalra irányítjuk.

Az App.vue router-view komponense előtt minden esetben betöltjük a Header

komponenst.

### 3.4 Header komponens

A Header komponens a felső navigációs menüt jeleníti meg. Itt lekérdezzük a felhasználó

jogosultsági szintjét a storeból, hogy csak olyan elemeket jelenítsünk meg a felhasználó

számára, amihez jogosultsága is van. Három fő menüvel rendelkezik. Az első az üzenőfal.

Ez csak a User és az Admin jogosultsággal rendelkező felhasználók számára jelenik meg,

mivel SuperAdmin számára ez nem értelmezett. A második menüpont a lekérdezés, ami

szintén ezekkel a jogosultsági körökkel elérhető. A harmadik menüpont a módosítás. Ez

a menüpont három almenüre bontható. Ez csak az Admin és SuperAdmin jogosultsági

körökkel elérhető, mivel a Usernek nincsen jóga módosítani. A menüpontok mellett itt

található meg a kijelentkezés gomb is. Megnyomására egy metódus hívás következik be,

amelynek hatására kitöröljük a storeban tárolt felhasználói adatokat.

3.4 1. ábra Header komponens Admin jogosultsággal

### 3.5 Üzenőfal komponens

Az üzenőfal komponensem azt a célt szolgálja, hogy az azonos üvegházhoz tartozó

felhasználók üzeneteket osszanak meg egymással. Az oldal létrehozásakor az axios

segítségével lekérdezzük az összes bejegyzést, majd megjelenítjük azokat. Az üzenetnél

megjelenítjük az üzenet írójának felhasználónevét, az üzenet létrehozásának időpontját és magát az üzenetet. Ezen a felületen van lehetőségünk az üzenet létrehozására is. Az „Új

üzenőfal hozzászólás” gomb megnyomására megjelenítünk egy modalt, ahol megadható

a fejléc és a szöveg. Ha kitöltöttük a mezőket, akkor a mentés gomb megnyomásával

elküldjük és mentésre kerül az adatbázisban. A küldés finally() függvény callback

részében újra töltjük az oldalt. Ezzel frissítjük a megjelenítendő üzenetek listáját.

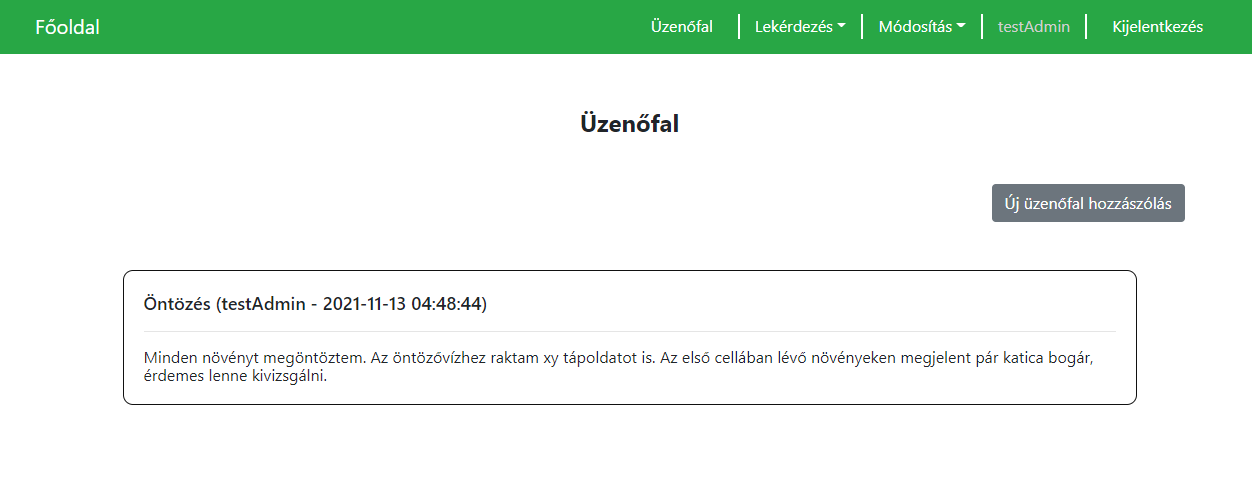
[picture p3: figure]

3.5 1. ábra Üzenőfal komponens

### 3.6 Lekérdezés komponens

A lekérdezések komponensnél lehetőségünk van megtekinteni a mérési adatokat. Annak

érdekében, hogy felhasználói szempontból jól kezelhető legyen, nem csak simán ki

listázzuk az összes mérést, hanem ki kell válasszuk, hogy melyik cellában lévő eszközök

adatait szeretnénk látni. A komponenst betöltésénél lekérdezzük, hogy a felhasználóhoz

rendelt üvegházban mennyi a maximum oszlopok és sorok száma. Ha ez megtörtént akkor

mind a két adatra legördülő listát jelenítünk meg a lehetséges értékekkel. Ezt a két értéket

kötelező megadni, ha ezeket megadtuk, akkor megjelennek a cellához tartozó eszközök.

Abban az esetben, ha nincs a cellához eszköz rendelve, üzenettel tájékoztatjuk a

felhasználót, hogy ebben a cellában nincs eszköz. Az eszközök megjelenítésénél az

eszköz dokumentum azonosítója és az eszköz azonosítója szerepel. Admin

felhasználóként megjelenik egy ikon is számunkra, amivel azonnali mérést

kezdeményezhetünk az eszközön. Ha azonnali mérést kezdeményezünk, akkor 2

másodpercig nem tudjuk újra megnyomni a gombot.

A mérési adatokat úgy tudjuk megtekinteni, hogy rá kattintunk az általunk

választott mikrovezérlő adatait tartalmazó területre. Ekkor megjelenik egy modal. A

modal megnyitásával elindítunk egy lekérdezést az adott eszköz adataira. Alaphelyzetben

minden mérési adatot megjelenítünk az adott eszközhöz. Lehetőségünk van az adatok

szűrésére, hogy csak egy bizonyos napon mért adatokat írjon ki. Ez azért kellett, mert ha

huzamosabb ideig mérünk az eszközzel akkor rengeteg adat közül kell ki keresnünk a

számunkra releváns adatot. A dátum kiválasztására egy dátum választót használok,

amelyből törölni is lehet a dátumot, ami azt eredményezi, hogy újra az összes mérési adat

megjelenik.

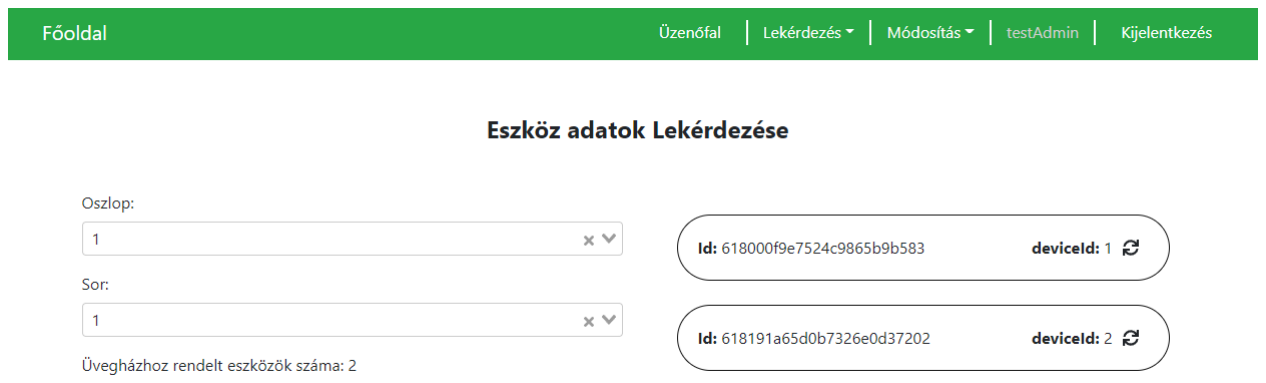
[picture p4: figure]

3.6 1. ábra Lekérdezések Admin felhasználóval

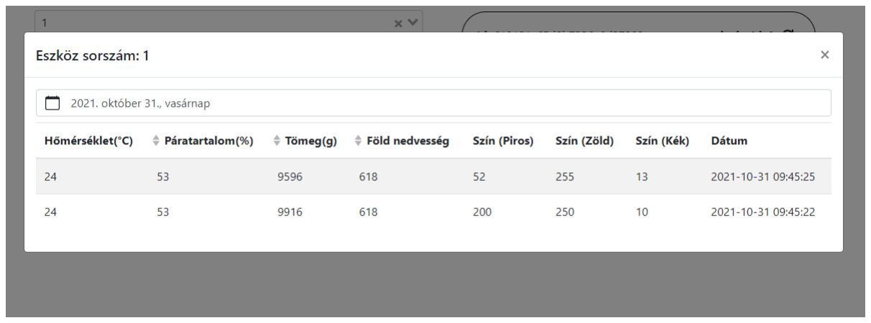
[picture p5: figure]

3.6 2. ábra Eszköz adatok modal

### 3.7 Módosítások menüpont

A módosítás menüpont alatt elérhető Admin felhasználók számára a felhasználók

módosítása, eszközök módosítása és az eszköz konfigurációt módosítása. SuperAdmin

felhasználóként pedig a felhasználók módosítása és az üvegházak módosítása.

A felhasználók módosításánál a már meglévő felhasználókat módosíthatjuk vagy

törölhetjük. A módosításnál Admin felhasználóként egyedül a jogosultságot lehet

változtatni, míg SuperAdmin felhasználóként üvegházat is tudunk rendelni egy

felhasználóhoz. Ennek az az oka, hogy a SuperAdmin hivatott arra, hogy üvegházhoz

felvegyen felhasználókat, mivel ő kezeli a rendszert. Felhasználók felvételére azért nincs

lehetőség, mert így minden regisztráló a saját titkos jelszavát tudja használni, amit a

SuperAdmin nem tud.

Eszközök módosításánál lehetőségünk van eszközöket törölni és új eszközöket

létrehozni. Az eszköz módosítása nem értelmezett mivel azzal valótlan képet adnának a

mérések. Gondoljunk csak bele abba, hogy egy eszköz egy ideig mér egy adott cellát,

majd valaki ezt át állítja. A mérési adatoknál nem vennénk észre azt, hogy az eszköz át lett helyezve és a mérésekben előfordulhat egy nagy törés a környezeti viszonyok

változása miatt.

Az eszközök konfigurációjának módosítása hasonló az adatok lekérdezéséhez. Ki

listázzuk az elérhető eszközöket, majd az eszköz adataira kattintva előjön egy modal, ahol

előre meghatározott értékek közül választhatunk.

SuperAdmin felhasználóként elérhető számunka az üvegházak módosítása. Itt

létre tudunk hozni új üvegházakat, láthatjuk a meglévő üvegházakat, módosíthatjuk

azokat és még törölni is tudunk. Itt tudjuk megadni az üvegház cellákra osztásához

szükséges oszlopok és sorok számát.

### 4. Monitorozó eszközök

A növények monitorozásához két mikrovezérlőt használok. Az egyik ilyen mikrovezérlő

az STM32L452RE-P a másik pedig a Heltec WiFi LoRa 32 (V1). A mikrovezérlők

tökéletes eszközök az általam definiált feladat ellátására. Előnyük, hogy kis helyen

elférnek és nagyon alacsony az energia fogyasztásuk. Nagyon sokoldalú eszközök és

egyszerűen bővíthetők. A mérnöki feladatok ellátásához sokszor figyelembe kell vennünk

a rendelkezésre álló eszközöket. Azért használtam két mikrovezérlőt, mivel az STM32

mikrovezérlő nem tartalmazott WiFi modult, de a már meglévő ESP32 alapú

mikrovezérlő igen. A másik előnye, hogy nagyobb jártasságot szereztem a mikrovezérlők

közötti kommunikáció megvalósításában is. Abban az esetben, ha a rendszerünket

bővíteni szeretnék, figyelembe kell vegyük azt is, hogy mekkora a fogyasztása bizonyos

szenzoroknak. Ebben is segítséget nyújthat a két mikrovezérlő használata.

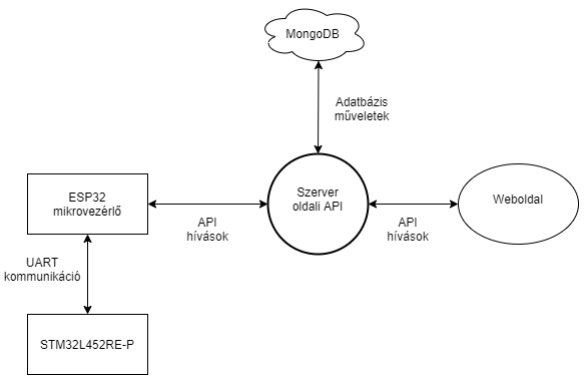
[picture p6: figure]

4. 1. ábra Rendszer felépítése

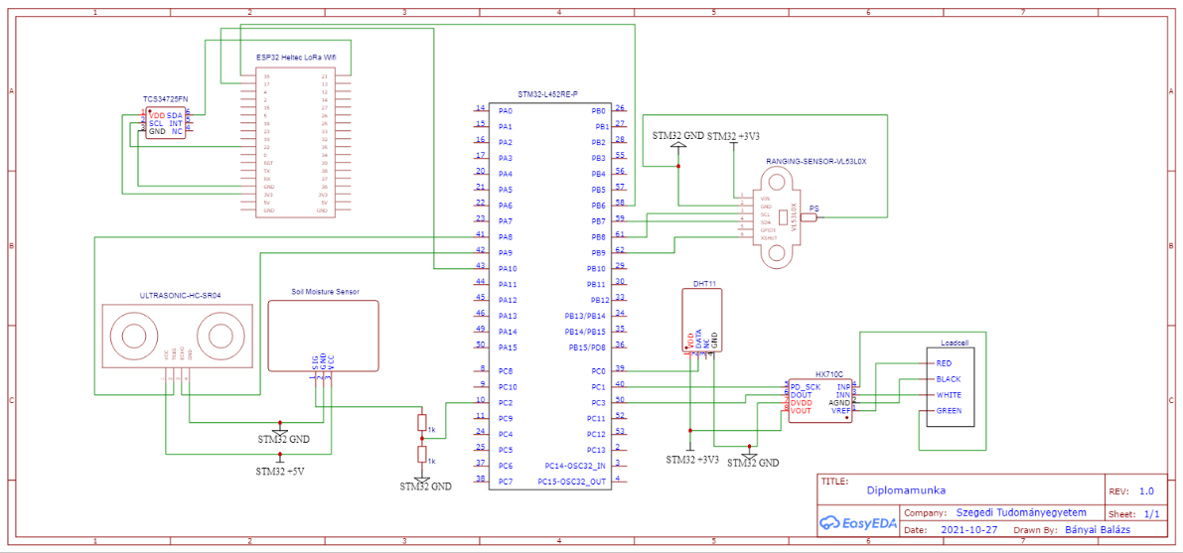
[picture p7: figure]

4. 2. ábra Mikrovezérlők kapcsolási rajza

### 4.1 ARM Cortex M alapú mikrovezérlő

A mikrovezérlő választásánál figyelembe vettem azt, hogy milyen eszközök állnak

rendelkezésemre. Ezért esett a választás az STM32L452RE-P típusú mikrovezérlőre.

A mikrovezérlő konfigurálására a gyártó által kiadott STM32CubeMX szoftvert

használtam. Lehetőségünk van kiválasztani az általunk használt mikrovezérlőt. Ez

alapján csak azok a beállítások lesznek számunkra elérhetők amire az eszközünk képes.

A konfigurációk megadása után generálhatunk kódot. A generálásnál ki kell választanunk a fejlesztő környezetet, amiben dolgozni szeretnénk. Én az Atollic Studio-t választottam

erre a célra. Miután a generálás megtörtént kód szinten is látjuk a beállításokat, amit az

STM32CubeMX-ben megadtunk. Az automata kód generálás és a fejlesztő környezet

előnye az is, hogy a projektünkhöz kezdésből rendelkezésre áll a HAL függvény

könyvtár. A HAL függvény könyvtár használatával egyszerűbben kezelhetjük a

mikrovezérlőt, mivel nem kell fejlesztés közben memóriacímeket írnunk és olvasnunk.

Ez azért lehetséges, mert ezek vannak leimplementálva a függvény könyvtárakban. Az

általam írt program C nyelven íródott, de van lehetőség más nyelveken is programozni az

eszközt.

### 4.2 ESP32 mikrovezérlő

Az ESP32 mikrovezérlő széles körben elterjedt eszköz. Olcsón beszerezhető és az árához

képest nagyon széleskörűen felhasználható. Mivel a rendszerben vezetéknélküli

kommunikációt valósítok meg, ezért egy olyan típusú mikrovezérlőt választottam,

amiben beépített WiFi modul található. Az előző mikrovezérlőhöz hasonlóan ez az eszköz

is több nyelven programozható. Mivel a rajta futó program bonyolultsága nem nagy, ezért

Arduino keretrendszer segítségével programoztam, amit sokan használnak egyszerűsége

miatt.

### 4.3 Távolság érzékelése ultrahang alapú szenzorral

A távolság érzékelését egy HC-SR04 szenzor segítségével valósítottam meg. Az

érzékelés azon az elven alapul, hogy az általa kiadott ultrahang vissza verődik a mérendő

felületen és érzékeli azt. A szenzor 4 lábbal rendelkezik. A GND a földelés, a VCC a

tápfeszültés, ami a szenzor esetében 5V. A mérés megkezdéséhez a Trig elnevezésű lábra

kell kiadnunk egy legalább 10μs hosszúságú impulzust. Ennek hatására nyolc ultrahang

jelet ad ki a szenzor. A kiadott jel érzékelése az Echo láb segítségével történik. Az Echo

jel a kiadott 8 impulzus után magas értéket vesz fel és mindaddig tartja ezt a magas

értéket, amíg vissza nem érkezett az általa kiadott jel. A szenzor mérési tartománya 2cm

és 4m között van. Ez azt jelenti, hogy az adatlap szerint a gyártó ezen értékek között

garantálja a megfelelő működést. A timer beállításánál az órajelet érdemes leosztani 80-

1 értékkel, mivel ebben az esetben a timer számlálója 1μs elteltével növeli az értékét.

A szenzor működéséhez egy digitális kimenetet és egy timert használtam fel. A

digitális kimenet szolgál arra, hogy kiadjuk a trigger impulzust, amivel elkezdődik a

mérés. A timer pedig arra szolgál, hogy az Echo lábon kiadott jel hosszát mérjük. A timernek van olyan beállítási lehetősége, hogy a mikrovezérlő egyik lábára kössünk egy

jelet és a timer akkor kezdje el a számolást amikor felfutó élt detektál. Alapvetően ezt a

beállítást alkalmaztam. A konfigurációban azt is megadtam, hogy ebben az esetben a

mikrovezérlő megszakítás kezelője léptesse be a programot egy úgynevezett interrupt

függvénybe. A szenzor működése ebben a függvényben lett implementálva. Ha felmenő

élt detektál akkor timer értékét elmenti és a timer konfigurációját át állítja, hogy lefutó élt

detektáljon. Ha újra beérkezünk ebbe a függvénybe, akkor az azt jelenti, hogy lefutó él

detektálása történt, azaz a jelünk megérkezett a szenzor vevő egységébe. Ekkor ismét

elmentjük az értéket és a két mért érték különbségéből tudunk távolságot számolni.

A távolság számításánál figyelembe kell vegyük azt, hogy milyen sebességgel

terjed a hang a közegben. A távolság számításának képlete a következő:

Distance =

Difference ∗ 0.34 cm
s
2

4.3 1. képlet Távolság számolása a kapott értékekből

A Distance a mért távolságot jelöli, a Difference a két eltárolt számláló érték különbségét,

a 0.34 a hangsebesség levegőben. A kettővel való osztásra azért van szükségünk, mivel

az ultrahang levegőben töltött idejét mérjük és a tárgy felé tartó és a visszaverődés utáni

időt is mérjük. A számítások után a végső érték egy milliméterben lévő érték lesz, amit

el kell tároljunk egy változóban, mivel ezt a későbbiekben el szeretnénk tárolni

adatbázisban. [17, 18]

### 4.4 Távolság érzékelése lézeres alapú szenzorral

A lézeres alapú távolság érzékelésére VL53L0X szenzort használtam. A rendszerbe való

beépítéshez már egy kész függvény könyvtárat alkalmaztam, amely elérhető az interneten. A kommunikációhoz az I²C (Inter-Integrated Circuit) interfészt használja. A

mikrovezérlő konfigurációjánál lehetőségünk van megadni a kommunikáció sebességét.

A sebességnél ki kell válasszuk a Fast Mode lehetőséget, ami 400KHz es sebességet állít

be. Ez az ajánlást a szenzor adatlapjában is olvashatjuk. A mérésnek az elve hasonló, mint

az előző fejezetben említett ultrahangos szenzor, de ez a szenzor a lézer jel levegőben

töltött idejéből számolja a távolságot.

A programba való integrálásához két fő függvényt használtam. Az egyik az

inicializálást végzi. A függvényben érdemes először az XSHUT lábon keresztül

újraindítani a szenzort. Ezt követően a használ függvény könyvtár segítségével

inicializáljuk a szenzorunkat, amivel létre is hozzuk a kapcsolatot a mikrovezérlő és a

szenzor között. A szenzor több egymás utáni lézer jelet is kiad és várja, hogy

megérkezzen. Az érzékelési módból négy darabot olvashatunk az adatlapban. Alap mód,

nagy pontosságú mód, nagy távolság mérési mód és gyors mérési mód. Az inicializáló

függvényben a nagy pontosságú módot választottam, mivel nem időkritikus a mérésünk,

ezért ez tűnt a legészszerűbbnek. A mérési módok között valójában annyi a különbség,

hogy mennyi ideig várja a lézer jel visszaverődését. A szenzor megfelelő működése abban

az esetben garantált, ha a tápfeszültsége 2.8V és 3.5V közé esik és a kőmérséklet -20°C

és 70°C között van.

A szenzor inicializálás után a readRangeSingleMillimeters() függvénnyel tudjuk

a távolságot mérni. Ahogy a függvény nevében is szerepel a mért távolságot

milliméterben kapjuk meg. Miután kiolvastuk az értéket azt el is tároljuk és a

későbbiekben bekerül az adatbázisba is. [19, 20]

### 4.5 Tömeg mérőcella

A tömeg mérésére a legelterjedtebb módszere a nyúlás mérő bélyegek használata. A

nyúlás mérő bélyeget egy felületre ragasztva képesek vagyunk mérni a felület

deformációját. A bélyeg egy vezetőréteg, amelynek a felület változására változik az

ellenállása. Mivel az ellenállás változás nagyon kis mértékű ezért különböző erősítése

módszereket és pontos mérést igényel a detektálása. A tömeg mérő cella mérőhíd

elrendezésben van megvalósítva. A mérőcellát egy HX711-es modulra kötve használom,

ami erre a célra lett kifejlesztve. A modul tartalmaz egy programozható erősítőt, amely

32, 64 és 128 erősítést tesz lehetővé az analóg jelen. Az erősítés után egy 24 bites analóg

digitális konverter segítségével digitalizáljuk a jelet. A modulban megtalálható egy

analóg feszültség szabályozó is, aminek az a szerepe, hogy a bemenő tápfeszültséget szabályozza. Így a modul tápfeszültsége 2.6V és 5.5V között lehet. A mikrovezérlővel

való kommunikációja hasonlít az SPI interfészhez. Generálnunk kell bizonyos számú

(kiválasztott erősítéstől függő) impulzust az SCK lábra és minden kiadott impulzusra egy

értéket tudunk kiolvasni a DT lábon. Tehát az SCK egy órajelnek felel meg, míg a DT

lábon keresztül történik az értékek kiolvasása.

A szenzor használatához már meglévő függvény könyvtárat használtam, ami

nyíltan elérhető a Github oldalon. A fentiekben és az adatlapon leírt műkődési elvet

implementálja. A mérőcella használatához először inicializálnunk kell azt. A könyvtárban

leírt strukturából létre kell hozzunk egy példányt. Meg kell adjuk, hogy a mikrovezérlők

lábai közül melyiket szeretnénk használni erre a célra. Majd megadjuk az erősítés

mértékét. Ha ezzel végeztünk meghívjuk a HX711_Tare() függvényt ami beállítja az

offsetet. Ez tulajdonképpen egy tárázás. Ha ezzel végeztünk akkor bármikor lekérhetjük

a szenzor által mért eredményt.

A fent lévő publikus könyvtár nem teljes mértékig bizonyult megfelelőnek így a

HX711_Value függvényben kis mértékű módosítást kellet végrehajtanom. A mérleg

pontos használatához szükségünk van egy skálázásra. Ezt úgy tudjuk megtenni, hogy a

mérleg értékét kiolvassuk üres állapotban, majd rá rakunk egy ismert tömeget és

kiolvassuk az értéket. Végül az alábbi képlettel tudjuk megadni a skálázási együtthatót:

Skála érték =

(Terℎelve mért érték − Üresen mért érték) Terℎelési tömeg [g]

4.5 1. képlet Mérleg skálázásának számítása

Az offsetet a tárázási funkcióval tudjuk megkapni. A skálázási együttható meghatározása

után már minden mérésnél használhatjuk ezt. A beolvasott értékből minden alkalommal

ki kell vonjuk az offsetet és el kell osztanunk a már meghatározott skála értékkel. Az

eljárás eredménye végül egy grammban meghatározott érték lesz. Abban az esetben

amikor beüzemeljük a rendszerünket figyelnünk kell arra, hogy indulásnál a mérendő

növény még ne legyen rajta a mérlegen, mivel akkor nem valós offsetet állítana be, ami

durva mérési hibához vezetne. [21, 22, 23]

### 4.6 Hőmérséklet és páratartalom mérése

A környezet hőmérsékletének és páratartalmának mérésére egy DHT11 szenzort

használok. Ennek a szenzornak előnye az, hogy elég jól ellenáll a környezeti hatásoknak,

3.3V és 5V tápfeszültséggel is üzemeltethető és az árához képest nagyon pontos mérésre

képes.

A használatához függvény könyvtárat használok. A kommunikációt egy digitális

láb segítségével és egy timerrel lehet megvalósítani. A timer azért kell, mert a kommunikációban μs nagyságrendű ideig kell bizonyos értéken tartanunk a GPIO láb

értékét. A timer konfigurációjánál 80-1 értékkel leosztjuk az alap órajelet. A

kommunikációhoz a digitális portot váltogatnunk kell. Egyszer kimenetként, egyszer

pedig bemenetként használjuk azt. A beolvasott adatból az első két byte felel a

páratartalomért és a második két byte a hőmérsékletért. Az értékek beolvasásához csak a

readDHT11() függvényt kell használjuk, mivel a szenzor kalibrálása nem szükséges. [24,

25]

### 4.7 Föld nedvesség érzékelése

A föld nedvességének egy kapacitív földnedvesség érzékelő szenzort alkalmaztam.

Tápfeszültségnek 5V-ot választottam. Annak érdekében, hogy a szenzoron mért jel

biztosan ne haladja meg a mikrovezérlő bemeneti feszültség maximumát, egy feszültség

osztó kapcsolást építettem. A feszültségosztó kapcsolással a mikrovezérlő bemenetén

lévő feszültség pontosan a fele annak, amit a szenzor kimenetén mérhetünk.

A szenzor kalibrálását úgy végezhetjük el, hogy meg mérjük a szárazon kiadott

értéket, majd egy pohár vízbe merítjük és ez lesz a skála két végpontja. A skálázás

számomra nem bizonyult egy jó módszernek, mivel nagyon eltérő eredményeket kaptam

attól függően, hogy a helységben milyen volt a levegő páratartalma, ezért az analóg

digitális konverter által mért értéket tárolom el az adatbázisba. Ez azért lehet egy jó

megoldás, mert főként az érték változását és nem a pontos értéket szeretnénk tudni.

### 4.8 Színek érzékelése

A színek érzékelésére egy TCS3472 szenzort alkalmazok, ami az előző szenzoroktól eltérően az ESP32 mikrovezérlővel van összekötve. Kommunikációra az I²C interfészt

használja. Az Arduino környezet által lehetőségünk van mások által megírt könyvtárakat

használni. Az alkalmazásomban az Adafruit által kiadott könyvtárat használom. A

könyvtár használata igen egyszerű. Létre kell hozni egy példányt, amiben megadhatjuk a

beállási időt és az erősítést, majd megkezdjük a kommunikációt a szenzorral. Ezek után

már csak be kell olvassuk az értékeket. A szenzorral lehetőségünk van érzékelni a piros,

zöld, kék, és a fehér értékeket. Mivel nekünk a fehér érték nem hordoz információt ezért

azt nem használom fel.

### 5. Mikrovezérlőn futó programok rövid leírása

Az STM32 mikrovezérlőn futó program végzi a mérések nagy részét, ezért fontos, hogy

megbízhatóan működjön. A program belépési pontja a main() függvény, amelynek az első

részében a konfigurációban megadott inicializálások hajtódnak végre. Amikor ez

megtörtént akkor inicializáljuk a szenzorjainkat a fentebb említett módokon. Szükségünk

van egy UART kommunikáció megvalósítására is, mivel ezen keresztül fognak

kommunikálni egymással a mikrovezérlők. Az inicializáláshoz tartozik az is, hogy

UART-on keresztül küldünk egy „S” karaktert az ESP32 mikrovezérlő számára, amely

ezt fogadja és visszaküldi az adatbázisban lévő eszközhöz tartozó mintavételezési időt.

Ha ez sikeresen megtörtént akkor ezt el is mentjük egy változóba. A main() függvényben

található egy végtelen while() ciklus ami a mikrovezérlő folyamatos futását biztosítja. Itt

történik a mérési eredmények lekérdezése is. A mikrovezérlőn be kell konfigurálni a

valós idejű órát, mivel ennek segítségével tudjuk időközönként elindítani a mérést. A

mérések két esetben indulnak el, az egyik az, amikor letelt a mérési időköz, a másik pedig

az, amikor azonnali mérést kezdeményezünk a weboldalon. Ekkor az ESP32

mikrovezérlő kap egy HTTP kérést és ennek hatására UART-on keresztül küld jelet az

STM32 mikrovezérlőnek. A mérések végeztével az adatot UART-on keresztül elküldjük

az ESP32 mikrovezérlőnek JSON formátumban.

Az ESP32 eszközön futó program nagyrészt a WiFi kommunikációért felelős. A

WiFi kapcsolat létesítéséhez meg kell adjuk a WiFi hálózat SSID-jét és jelszavát. Ha ez

is megtörtént akkor elindítunk egy HTTP szervert a mikrovezérlőn, amire majd az API

küldi a kéréseket. Annak érdekében, hogy a server oldali API elérje statikus IP-címzést

használok. A WiFi csatlakozás után kapcsolódunk a szín érzékelő szenzorhoz. A

továbbiakban figyeljük az UART és a HTTP szerverre érkező adatokat. Abban az esetben,

ha a HTTP szerver „/measure” végpontot hívjuk, akkor UART adatot küldünk az STM32

mikrovezérlőnek, ami ennek hatására azonnali mérést kezdeményez. A „/config”

végpontra érkező kérés hatására pedig lekérdezzük az API-tól az adott mikrovezérlő

mintavételezési idejét és UART-on továbbítjuk.

Az UART-on érkező jelek feldolgozásának két esete van, az egyik az, amikor egy

’S’ karaktert kapunk. Ebben az esetben ugyan az történik, mint a „/config” végpont

hívásánál. A másik eset mikor adatot kapunk JSON formában. Ekkor elkezdjük a színek

érzékelését. Ha ezzel végeztünk akkor a JSON formátumban kapott adatot kibontjuk és hozzá fűzzük a mért szín adatokat, majd elküldjük az erre a célra létrehozott API

végpontra.

### 6. Rendszer tesztelése

A rendszer tesztelésére nem volt lehetőségem valós környezetben, ezért kialakítottam egy

saját tesztkörnyezetet. A saját tesztkörnyezetben arra törekedtem, hogy minél életszerűbb

legyen a megvalósítás.

A szenzorok elhelyezéséhez készítenem kellett egy keretet, mivel a növény

magasságának méréséhez a távolság mérésére alkalmas szenzorokat a növény felett

kellett elhelyeznem. A tömeg mérésére alkalmas súly mérő cella a kis mérete miatt nem

tartotta volna meg a növényt. Azért, hogy a tömeg mérését megvalósítsam terveztem egy

tartót, amire a növény helyezem. Ezt 3D nyomtatással valósítottam meg. Az elvárásoknak

megfelelően stabilan tartja a növényt.

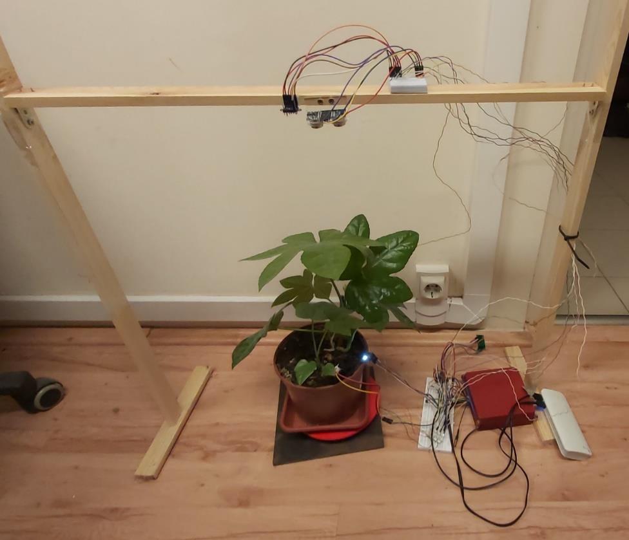
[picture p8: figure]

6. 1. ábra Teszt környezet mérés közben

Az eredmények fedik a valóságot egy szenzor kivételével. Ez a szenzor a szín

érzékelésére használt szenzor. A továbbiakban érdemes lehet ezt lecserélni egy jobb minőségű szenzorra. A tesztelés során a mikrovezérlőről másodpercenként küldtem az

eredményeket annak érdekében, hogy a kis változások is látszódjanak az eredményeken.

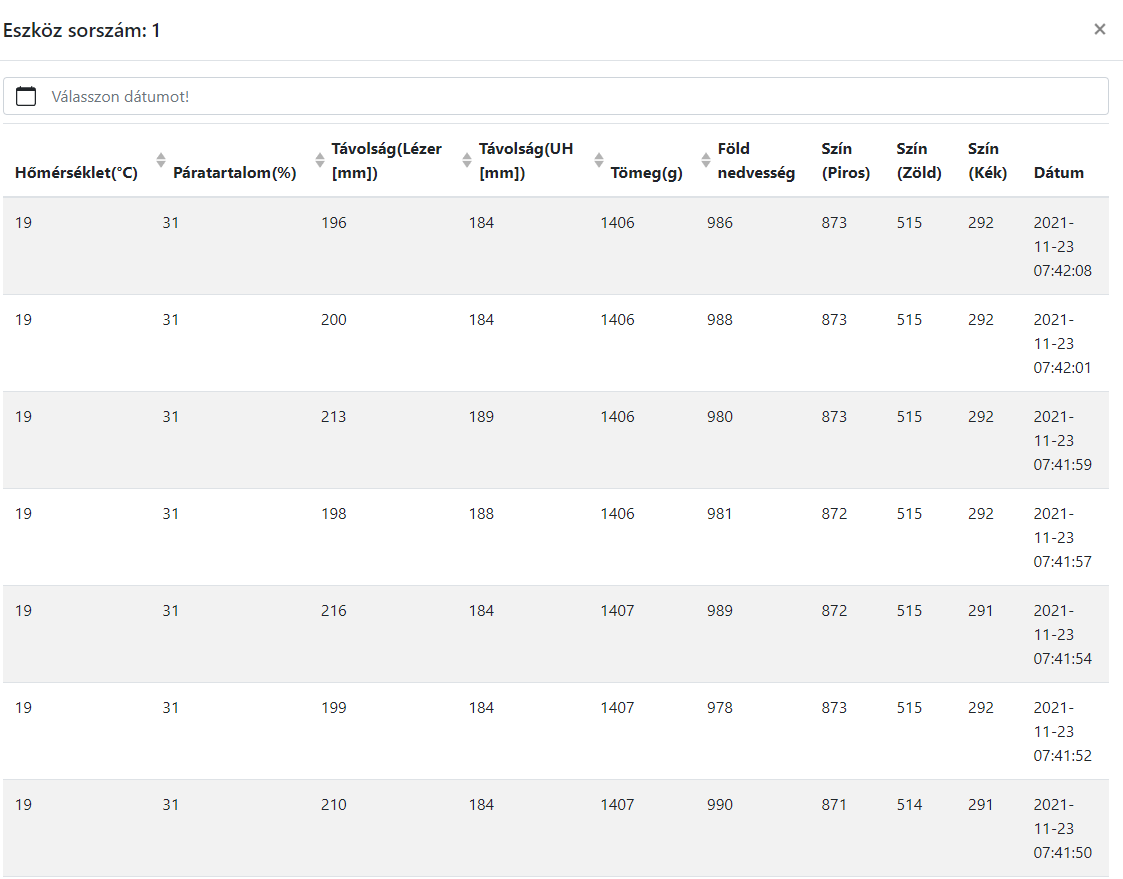
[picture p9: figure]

6. 2. ábra Mérési eredmények a weboldalon megjelenítve

### 7. Eszközök sérülésének elkerülése

Annak érdekében, hogy a mikrovezérlőket megvédjem a magas páratartalom okozta

sérülésektől terveznem kellet egy dobozt, ami nem engedi be a párát. Erre a

legalkalmasabb megoldásnak a 3D nyomtatást találtam. Mivel a Szegedi

Tudományegyetem Műszaki Informatika Tanszékén rendelkezésre álltak a hozzá

szükséges eszközök. A 3D modell megtervezéséhez az Autodesk Fusion 360 szoftvert

használtam. A nyomtatáshoz nem elegendő ennek a szoftvernek a használata,

megismerkedtem a Prusa Slicer szoftverrel, ami kifejezetten a Prusa 3D nyomtatókhoz

lett fejlesztve. A doboz nyomtatásához a megjelölt forrás alapján a PETG anyag bizonyult

a legmegfelelőbbnek az elérhető anyagok közül. A Prusa Slicerben lehetőségünk van

betölteni anyagtól függő beállításokat. A nyomtatási beállításoknál az alapértelmezett

beállításokon kis mértékű módosításokat kellett csináljak. A nyomtató fej hőmérsékletét

5°C meg kellett emeljem, annak érdekében, hogy a rétegek sokkal jobban egybe

olvadjanak és ne legyenek rések, a filament adagolási sebességét pedig megemeltem

20%-kal. Ezen felül a rögzítéshez használt fülek nyomtatásához segédanyagot kellet

használni, mivel a nyomtató nem képes alátámasztás nélkül bonyolultabb alakzatokat nyomtatni. A nyomtató padon fekvő elemek a hőváltozás hatására hajlamosak meghajolni

ezért egy úgynevezett brim réteget is hozzá kellett adjak a nyomtatáshoz, aminek

következtében sikerült úgy kinyomtatni a doboz részeit, hogy nem látható rajtuk

meghajlás.

Azon felül, hogy a mikrovezérlőnek tervezni kellett egy dobozt, tervezni kellett

egy felületet, amit rögzíteni tudok a mérőcellára. Az elvárás az volt ezzel szemben, hogy

elbírjon egy átlagos növényt. Mivel a mérőcella csak 5kg tömegig mér, ezért elégséges

volt ezt a tömeget elbírja. A mérlegre tervezett felület PLA anyagból lett nyomtatva, ami

végül olyan erősnek bizonyult, hogy elbírja a kívánt tömeget. Az általam tervezett 3D

modellek a mellékletben elérhetőek. [26]

Összegzés

A feladatkiírásban szereplő feladatokat sikerült maradéktalanul megoldanom.

Végeredményként egy olyan rendszer sikerült kiépítenem, amely alkalmas növények és

környezetük monitorozására. A mért adatok elég jól fedik a valóságot és a rendszer ezeket

az adatokat képes el is tárolni. A webes kezelőfelület teljes mértékben ellátja a rá bízott

funkciókat, de van lehetőség további funkciók bevezetésére is. A szerver oldali

alkalmazás megfelelőnek bizonyult arra a célra, hogy összekapcsolja az adatbázis, a

weboldalt és a mikrovezérlőket. Az adatbázis alkalmas arra, hogy nagy mennyiségű

adatot tároljunk benne és a felhőnek köszönhetően mindig és mindenhol elérhető. A

továbbiakban érdemes lehet átgondolni, hogy milyen szolgáltatónál lenne érdemes az

adatbázist futtatni, mivel különböző és folytonosan változó árazással rendelkeznek. A

feladat elvégzése során sikerült alaposabban megismerkednem a szenzorokkal és a

mikrovezérlők nyújtotta lehetőségekkel. Ezen felül kitapasztaltam, hogy hogyan lehet 3D

modelleket tervezni, majd azokat kinyomtatni 3D nyomtató segítségével. A feladat

kiírásnak megfelelően sikerült egy zárt dobozt terveznem, ami igényes megjelenésű.

A rendszert nem volt lehetőségem valós környezetben kipróbálni, de érdemes

lenne megtenni ezt a lépést a jövőben. A tesztelés által összegyűjtött tapasztalatok alapján

lehetne tovább fejleszteni a rendszert és beleépíteni azokat az észrevételeket, amik a

tesztelési folyamat közben jönnek elő. Továbbá érdemes lehet egy olyan módszert

kidolgozni, amivel le tudunk fedni egy nagy méretű üvegházat is kis eszközszámmal. Érdemes lenne a 3D nyomtatott dobozt huzamosabb időre magas páratartalmú

környezetbe helyezni, hogy meg lehessen bizonyosodni annak hatékonyságáról.

Irodalomjegyzék

[1] MongoDB – Why use MongoDB: https://www.mongodb.com/why-use-mongodb (megtekintve: 2021.11.10.)
[2] MongoDB – Document Databases: https://www.mongodb.com/document-databases (megtekintve: 2021.11.10.)
[3] MongoDB – Non-relational databases: https://www.mongodb.com/databases/non-relational (megtekintve: 2021.11.10.)
[4] Dr. Balázs Péter – NoSQL adatbázis-kezelők: http://www.inf.u-szeged.hu/~pbalazs/teaching/nosql_adatbaziskezeles.pdf (http://www.inf.u-szeged.hu/~pbalazs/teaching/nosql_adatbaziskezeles.pdf) (megtekintve: 2021.11.10.)
[5] JSON: https://www.json.org/json-en.html (megtekintve: 2021.11.10.)
[6] MongoDB Atlas - Database: https://www.mongodb.com/atlas/database (megtekintve: 2021.11.10.)
[7] MongoDB Atlas - Multi-cloud Data Distribution: https://www.mongodb.com/cloud/atlas/multicloud-data-distribution (https://www.mongodb.com/cloud/atlas/multicloud-data-distribution) (megtekintve: 2021.11.10.)
[8] NodeJS: https://nodejs.org/en/about/ (megtekintve: 2021.11.11.)
[9] npm: https://docs.npmjs.com/about-npm (megtekintve: 2021.11.11.)
[10] Express: https://expressjs.com (megtekintve: 2021.11.11.)
[11] Besant Technologies - What is Express.Js: https://www.besanttechnologies.com/what-is-expressjs (megtekintve: 2021.11.11.)
[12] Express - Install: https://expressjs.com/en/starter/installing.html (megtekintve: 2021.11.11.)
[13] JWT.io: https://jwt.io/introduction (megtekintve: 2021.11.12.)
[14] npmjs - jsonwebtoken: https://www.npmjs.com/package/jsonwebtoken (megtekintve: 2021.11.12.)
[15] Vue.Js - Introduction: https://vuejs.org/v2/guide/ (megtekintve: 2021.11.13.)
[16] BootstrapVue: https://bootstrap-vue.org (megtekintve: 2021.11.13.)
[17] ControllesTech - HCSR04 Ultrasonic sensor and STM32: https://controllerstech.com/hcsr04-ultrasonic-sensor-and-stm32/ (https://controllerstech.com/hcsr04-ultrasonic-sensor-and-stm32/) (megtekintve: 2021.11.20.)
[18] Hestore - HC-SR04 adatlap: https://www.hestore.hu/prod_getfile.php?id=8286 (megtekintve: 2021.11.20)
[19] ST Community - ZVita: https://community.st.com/s/question/0D50X00009XkWI2SAN/ported-vl53l0x-pololu-code-to-stm32-always-times-out-cant-find-error (https://community.st.com/s/question/0D50X00009XkWI2SAN/ported-vl53l0x-pololu-code-to-stm32-always-times-out-cant-find-error) (megtekintve: 2021.11.20.)
[20] Hestore – VL53L0X adatlap: https://www.hestore.hu/prod_getfile.php?id=9725 (megtekintve: 2021.11.20.)
[21] Gingl Zoltán – Elektronika I, Műszererősítők: http://www.inf.u-szeged.hu/~gingl/hallgatoknak/elektronika1/muszererositok.html (http://www.inf.u-szeged.hu/~gingl/hallgatoknak/elektronika1/muszererositok.html) (megtekintve: 2021.11.20.)
[22] Hestore – HX711 adatlap: https://www.hestore.hu/prod_getfile.php?id=9723 (megtekintve: 2021.11.20.)
[23] Github, freakone – HX711 függvény könyvtár: https://github.com/freakone/HX711 (megtekintve: 2021.11.20.)
[24] Github,, mesutkilic – DHT11-STM32-Library: https://github.com/mesutkilic/DHT11-STM32-Library (https://github.com/mesutkilic/DHT11-STM32-Library) (megtekintve: 2021.11.20.)
[25] Umang Gajera: Basics of Interfacing DHT11/DHT22 Humidity and Temperature Sensor with MCU: http://www.ocfreaks.com/basics-interfacing-dht11-dht22-humidity-temperature-sensor-mcu/(megtekintve: 2021.11.20.)
[26] Prusa Knowledge Base – Watertight prints: https://help.prusa3d.com/en/article/watertight-prints_112324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 (https://help.prusa3d.com/en/article/watertight-prints_112324) (megtekintve: 2021.11.20.)

Nyilatkozat

Alulírott Bányai Balázs mérnökinformatikus MSc szakos hallgató, kijelentem,

hogy a dolgozatomat a Szegedi Tudományegyetem, Informatikai Intézet Műszaki

Informatika Tanszékén készítettem, Msc diploma megszerzése érdekében.

Kijelentem, hogy a dolgozatot más szakon korábban nem védtem meg, saját

munkám eredménye, és csak a hivatkozott forrásokat (szakirodalom, eszközök, stb.)

használtam fel.

Tudomásul veszem, hogy diplomamunkámat a Szegedi Tudományegyetem

Informatikai Intézet könyvtárában, a helyben olvasható könyvek között helyezik el.

2021.11.29.

Aláírás

Köszönetnyilvánítás

Köszönetet szeretnék mondani a témavezetőmnek, Dr. Mingesz Róbert Zoltánnak, aki

sok segítséget nyújtott a témával és a 3D nyomtatással kapcsolatban. Illetve családomnak

és barátaimnak, akik mindig támogattak egyetemi tanulmányaim alatt.

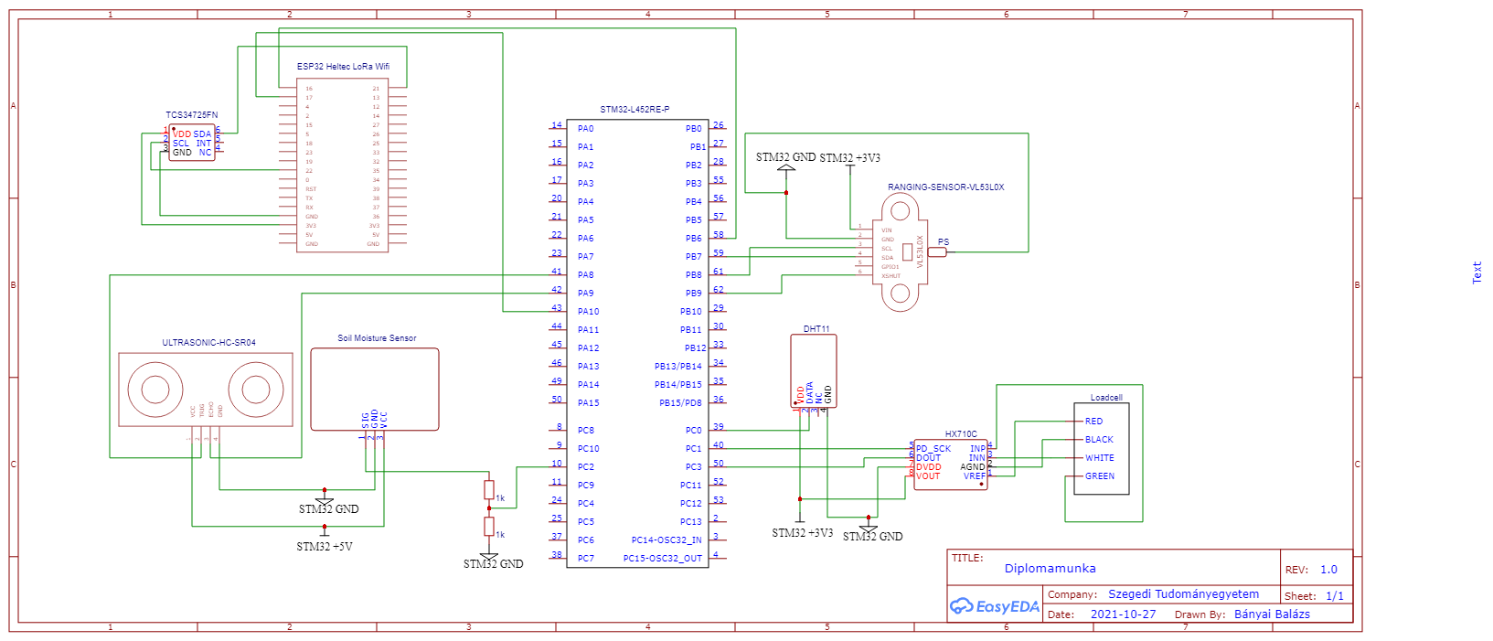
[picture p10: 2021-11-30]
abrak_egyeb/Schematic_kapcsolas_diplomamunka_2_2021-11-23.png

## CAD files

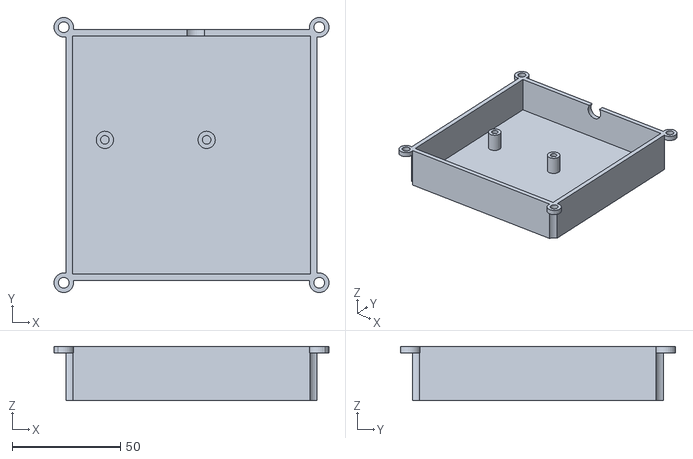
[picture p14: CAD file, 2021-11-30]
abrak_egyeb/mc_box_bottom_menetes.stl
127.0 x 127.0 x 25.0

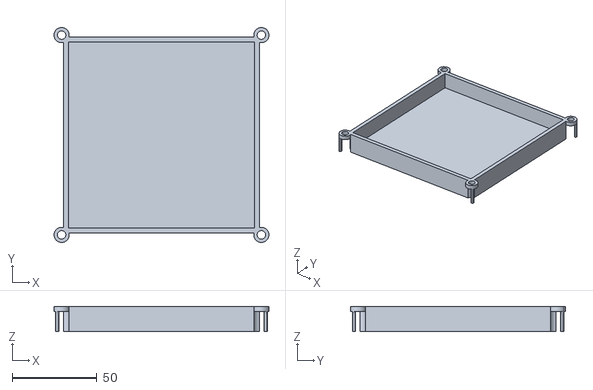
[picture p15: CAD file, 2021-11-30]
abrak_egyeb/mc_box_top_fixed.stl
127.0 x 127.0 x 15.0

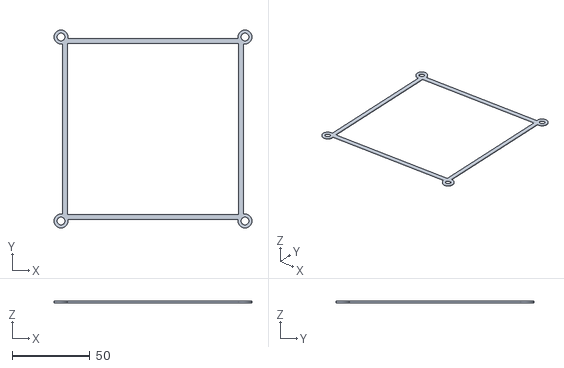
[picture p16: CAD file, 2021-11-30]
abrak_egyeb/mc_box_flexible.stl
127.0 x 127.0 x 1.00

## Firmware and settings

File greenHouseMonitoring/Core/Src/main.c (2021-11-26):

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
/* Includes ------------------------------------------------------------------*/
#include "main.h"

/* USER CODE BEGIN Includes */
#include "stm32l452xx.h"
#include "stdio.h"
#include "string.h"
#include "VL53L0X.h"
#include "I2CDev.h"
#include "mk_dht11.h"
#include "hx711.h"
/* USER CODE END Includes */

/* USER CODE BEGIN PTD */

// sensor meresi adatok strukturaja
typedef struct
{
  uint16_t laser_sensor_distance;
  uint16_t ultra_sonic_sensor_distance;
  uint8_t temperature;
  uint8_t humidity;
  unsigned long weight;
  uint16_t moisture;
} SENSOR_VALUES_TYPE;


/* USER CODE END PTD */

/* USER CODE BEGIN PD */
#define LOAD_CELL_SCALE 379
#define DEVICE_ID 1
/* USER CODE END PD */

ADC_HandleTypeDef hadc1;

I2C_HandleTypeDef hi2c1;

RTC_HandleTypeDef hrtc;

TIM_HandleTypeDef htim1;
TIM_HandleTypeDef htim6;

UART_HandleTypeDef huart1;
UART_HandleTypeDef huart2;

/* USER CODE BEGIN PV */
// sensor struct peldany
SENSOR_VALUES_TYPE sensor_values;

// uj sor a kiiratas fuggvenyhez
char newLine [] = "\n\r";

// realtime clock datum es ido
RTC_DateTypeDef rtc_date;
RTC_TimeTypeDef rtc_time;

// meresi idokoz percben
uint8_t measurement_time = 10;

// laser distance sensor struct peldany
VL53L0X sensor1;

// ultra sonic sensor segedvaltozok
uint32_t ultra_sonic_rising = 0;
uint32_t ultra_sonic_falling = 0;
uint32_t ultrasonic_difference = 0;
uint8_t ultra_sonic_frist_captured = 0;

// DHT11-MK sensor struct peldany
dht11_t dht_sensor;

// HX711 loadcell struct peldany
HX711 loadcell_sensor;

// UART-on erkezett adatok tarolasa
char uart_buffer[10] = "";

// azonnali meres kezdemenyezese
uint8_t rapidMeasure;
/* USER CODE END PV */

void SystemClock_Config(void);
static void MX_GPIO_Init(void);
static void MX_ADC1_Init(void);
static void MX_I2C1_Init(void);
static void MX_RTC_Init(void);
static void MX_TIM1_Init(void);
static void MX_USART1_UART_Init(void);
static void MX_USART2_UART_Init(void);
static void MX_TIM6_Init(void);
/* USER CODE BEGIN 0 */
 /**
  * Uzenet kiirasa consolera UART2 keresztul
  *
  * @param char message[]
  */
  void PrintMessage(char message[])
  {
	  HAL_UART_Transmit(&huart2,message, strlen(message), HAL_MAX_DELAY);
  }

  /**
   * Szam kiirasa consolera UART2 keresztul
   *
   * @param uint16_t number
   */
  void PrintNumber(uint16_t number)
    {
	  char converted_number[6];
	  sprintf(converted_number, "%d", number);
  	  PrintMessage(converted_number);
    }

  /**
   * Uj sor kiirasa consolera UART2 keresztul
   */
  void PrintNewLine()
  {
	  HAL_UART_Transmit(&huart2, (uint8_t*)newLine, sizeof(newLine), HAL_MAX_DELAY);
  }


  /**
   * RTC ido lekerdezese
   */
  void getTime()
  {
	  HAL_RTC_GetTime(&hrtc, &rtc_time, RTC_FORMAT_BIN);
	  HAL_RTC_GetDate(&hrtc, &rtc_date, RTC_FORMAT_BIN);
  }

  /**
   * Laser distance sensor inicializalasa
   */
  void initLaserDistanceSensor()
  {
	  setup_VL53L0X(&sensor1);
	  HAL_GPIO_WritePin(LASER_DISTANCE_XSHUT_GPIO_Port, LASER_DISTANCE_XSHUT_Pin, GPIO_PIN_RESET);
	  HAL_Delay(100);

	  HAL_GPIO_WritePin(LASER_DISTANCE_XSHUT_GPIO_Port, LASER_DISTANCE_XSHUT_Pin, GPIO_PIN_SET);
	  HAL_Delay(100);
	  if(!init(&sensor1,true))
	  {
			  PrintMessage("Laser Distance sensor inicializalas sikertelen");
			  PrintNewLine();
	  }
	  else
	  {
		  PrintMessage("Laser Distance sensor inicializalas sikeres");
		  PrintNewLine();
	  }
	  setTimeout(&sensor1,500);

	  setVcselPulsePeriod(&sensor1,VcselPeriodPreRange, 18);
	  setVcselPulsePeriod(&sensor1,VcselPeriodFinalRange, 14);
	  setMeasurementTimingBudget(&sensor1,200000);
  }

  /**
   * Laser distance sensor ertek beolvasas
   */
  void readLaserDistanceValue()
  {
	  sensor_values.laser_sensor_distance = readRangeSingleMillimeters(&sensor1);
  }

  /**
   * Ultrasonic distance sensor ertek beolvasas
   */
  void ultraSonicDisctanceRead(void) {
  	HAL_GPIO_WritePin(ULTRA_SONIC_TRG_GPIO_Port, ULTRA_SONIC_TRG_Pin, GPIO_PIN_SET);
  	HAL_Delay(100);
  	HAL_GPIO_WritePin(ULTRA_SONIC_TRG_GPIO_Port, ULTRA_SONIC_TRG_Pin, GPIO_PIN_RESET);
  	__HAL_TIM_ENABLE_IT(&htim1, TIM_IT_CC2);
  }

  /**
   * Homerseklet es paratartalom ertek beolvasas
   */
  void measureTemperatureAndHumidity()
  {
	  readDHT11(&dht_sensor);
	  sensor_values.temperature = dht_sensor.temperature;
	  sensor_values.humidity = dht_sensor.humidty;
  }

  /**
   * Suly cella inicializalas
   */
  void loadCellInit()
  {
	  loadcell_sensor.gpioData = LOAD_CELL_DT_GPIO_Port;
	  loadcell_sensor.gpioSck = LOAD_CELL_CLK_GPIO_Port;
	  loadcell_sensor.pinData = LOAD_CELL_DT_Pin;
	  loadcell_sensor.pinSck = LOAD_CELL_CLK_Pin;
	  loadcell_sensor.gain = 128;
	  loadcell_sensor.offset = 0;

	  HX711_Init(loadcell_sensor);
	  HAL_Delay(2000);
	  loadcell_sensor =  HX711_Tare(loadcell_sensor, 1);

  }

  /**
   * Tomeg mero cella ertek beolvasas es skalazasa
   */
  void measureWeight()
  {
	  sensor_values.weight = ((HX711_Value(loadcell_sensor) - (unsigned long)loadcell_sensor.offset) / LOAD_CELL_SCALE);
  }

  /**
   * Fold nedvesseg ertek beolvasas
   */
  void measureSoilMoisture()
  {
	  HAL_ADC_Start(&hadc1);
	  sensor_values.moisture =  HAL_ADC_GetValue(&hadc1);
	  HAL_ADC_Stop(&hadc1);
  }

  /**
   * JSON adat kuldese az ESP32 mikrovezerlonek
   */
  void sendJSONData()
  {
	  char jsonData[1000]= "";
	  sprintf(jsonData,
			  "{\"deviceId\": %d, \"laserDistance\": %d, \"sonicDistance\": %d,"
			  " \"temperature\": %d, \"humidity\": %d, \"weight\": %d, \"moisture\": %d}",
			  DEVICE_ID,
			  sensor_values.laser_sensor_distance,
			  sensor_values.ultra_sonic_sensor_distance,
			  sensor_values.temperature,
			  sensor_values.humidity,
			  sensor_values.weight,
			  sensor_values.moisture
			  );
	  HAL_UART_Transmit(&huart1, jsonData, strlen(jsonData), HAL_MAX_DELAY);
  }

  /**
   * Az osszes sensor adat beolvasasa
   */
  void measureAllData() {
	  readLaserDistanceValue();
	  PrintMessage("laser sensor ertek: ");
	  PrintNumber(sensor_values.laser_sensor_distance);
	  PrintNewLine();
	  ultraSonicDisctanceRead();
	  PrintMessage("us sensor ertek: ");
	  PrintNumber(sensor_values.ultra_sonic_sensor_distance);
	  PrintNewLine();
	  measureTemperatureAndHumidity();
	  PrintMessage("temp sensor ertek: ");
	  PrintNumber(sensor_values.temperature);
	  PrintNewLine();
	  PrintMessage("hum sensor ertek: ");
	  PrintNumber(sensor_values.humidity);
	  PrintNewLine();
	  measureWeight();
	  PrintMessage("weight sensor ertek: ");
	  PrintNumber(sensor_values.weight);
	  PrintNewLine();
	  measureSoilMoisture();
	  PrintMessage("moisture sensor ertek: ");
	  PrintNumber(sensor_values.moisture);
	  PrintNewLine();
  }

  void I2C_Read_Byte(uint8_t addr,uint8_t *data)
  {
   while (HAL_I2C_GetState(&hi2c1) != HAL_I2C_STATE_READY);
  if(HAL_I2C_Master_Transmit(&hi2c1,  SLAVE_ADDRESS<<1 , &addr,  1, 100)!=HAL_OK)
    {
        _Error_Handler(__FILE__, __LINE__);
    }
  while (HAL_I2C_GetState(&hi2c1) != HAL_I2C_STATE_READY);
  if(HAL_I2C_Master_Receive(&hi2c1, ((SLAVE_ADDRESS <<1) | 0x01), data, 1, 100)!=HAL_OK)
    {
       _Error_Handler(__FILE__, __LINE__);
    }
  }

  void I2C_Write_Byte(uint8_t addr, uint8_t data)
  {
    uint8_t buf[] = {addr, data};
    while (HAL_I2C_GetState(&hi2c1) != HAL_I2C_STATE_READY);
    if(HAL_I2C_Master_Transmit(&hi2c1, SLAVE_ADDRESS<<1, buf, 2, 100)!=HAL_OK)
      {
        _Error_Handler(__FILE__, __LINE__);
      }
  }

  void readMulti(VL53L0X * lidar,uint8_t reg, uint8_t * dst, uint8_t count)
   {
       /* Send register address */
       if (HAL_I2C_Master_Transmit(&hi2c1, SLAVE_ADDRESS<<1, &reg, 1, 1000) != HAL_OK)
         {
           {
               _Error_Handler(__FILE__, __LINE__);
           }
         }

       /* Receive multiple byte */
       if (HAL_I2C_Master_Receive(&hi2c1, ((SLAVE_ADDRESS <<1) | 0x01), dst, count, 1000) != HAL_OK)
         {
            _Error_Handler(__FILE__, __LINE__);
         }
   }

   void writeMulti(VL53L0X * lidar,uint8_t reg, uint8_t* src, uint8_t count)
   {
            /* Try to transmit via I2C */
           if(HAL_I2C_Mem_Write(&hi2c1, SLAVE_ADDRESS<<1, reg, reg>0xFF ? I2C_MEMADD_SIZE_16BIT : I2C_MEMADD_SIZE_8BIT, src, count, 1000) != HAL_OK)
               {
                  _Error_Handler(__FILE__, __LINE__);
               }

   }
/* USER CODE END 0 */

/**
  * @brief  The application entry point.
  * @retval int
  */
int main(void)
{
  /* MCU Configuration--------------------------------------------------------*/

  /* Reset of all peripherals, Initializes the Flash interface and the Systick. */
   HAL_Init();

  /* Configure the system clock */
  SystemClock_Config();

  /* Initialize all configured peripherals */
  MX_GPIO_Init();
  MX_ADC1_Init();
  MX_I2C1_Init();
  MX_RTC_Init();
  MX_TIM1_Init();
  MX_USART1_UART_Init();
  MX_USART2_UART_Init();
  MX_TIM6_Init();
  /* USER CODE BEGIN 2 */

  // sensor inicializalasok
  initLaserDistanceSensor();
  HAL_TIM_IC_Start_IT(&htim1, TIM_CHANNEL_2);
  init_dht11(&dht_sensor, &htim6, DHT11_GPIO_Port, DHT11_Pin);
  loadCellInit();
  measureAllData();
  HAL_UART_Receive_IT(&huart1, uart_buffer, 2);
  HAL_UART_Transmit(&huart1, "S", 1, HAL_MAX_DELAY);
  /* USER CODE END 2 */

  /* Infinite loop */
  /* USER CODE BEGIN WHILE */
  while (1)
  {
    /* USER CODE END WHILE */

    /* USER CODE BEGIN 3 */
	  if((rtc_time.Seconds == 0 && (rtc_time.Minutes % measurement_time) == 0))
	  {
		  measureAllData();
		  sendJSONData();
	  }

	  if(rapidMeasure == 1)
	  {
		measureAllData();
		sendJSONData();
		rapidMeasure = 0;
	  }

	  getTime();
	  HAL_Delay(1000);
  }
  /* USER CODE END 3 */
}

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
/* USER CODE BEGIN 4 */
void _Error_Handler(char *file, int line)
{
  /* USER CODE END Error_Handler_Debug */
}

// Timer az ultrahang tavolsag szenzor ertekenek olvasasara
void HAL_TIM_IC_CaptureCallback(TIM_HandleTypeDef *htim) {

	if (htim->Channel == HAL_TIM_ACTIVE_CHANNEL_2) {
		if (ultra_sonic_frist_captured == 0) {
			ultra_sonic_rising = HAL_TIM_ReadCapturedValue(htim, TIM_CHANNEL_2);
			ultra_sonic_frist_captured = 1;
			__HAL_TIM_SET_CAPTUREPOLARITY(htim, TIM_CHANNEL_2,
					TIM_INPUTCHANNELPOLARITY_FALLING);
		} else if (ultra_sonic_frist_captured) {
			ultra_sonic_falling = HAL_TIM_ReadCapturedValue(htim, TIM_CHANNEL_2);
			__HAL_TIM_SET_COUNTER(htim, 0);
			if (ultra_sonic_falling > ultra_sonic_rising) {
				ultrasonic_difference = ultra_sonic_falling - ultra_sonic_rising;
			} else if (ultra_sonic_rising > ultra_sonic_falling) {
				ultrasonic_difference = (65535 - ultra_sonic_rising) + ultra_sonic_falling;
			}
			sensor_values.ultra_sonic_sensor_distance = ultrasonic_difference * 0.34 / 2;
			ultra_sonic_frist_captured = 0;
			__HAL_TIM_SET_CAPTUREPOLARITY(htim, TIM_CHANNEL_2,
					TIM_INPUTCHANNELPOLARITY_RISING);
			__HAL_TIM_DISABLE_IT(htim, TIM_IT_CC2);

		}
	}
}

// Interrupt callback az UART-on erkezo adatokra
void HAL_UART_RxCpltCallback(UART_HandleTypeDef *huart)
{
    HAL_UART_Receive_IT(&huart1, uart_buffer, 2);

	if (uart_buffer[0] == '0')
	{
		rapidMeasure = 1;
	}
	else
	{
		sscanf (uart_buffer,"%d",&measurement_time);
	}
}
/* USER CODE END 4 */
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


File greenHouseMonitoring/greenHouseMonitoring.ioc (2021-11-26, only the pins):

Mcu.UserName=STM32L452RETxP
PA10.Signal=USART1_RX
PA2.Signal=USART2_TX
PA8.GPIO_Label=ULTRA_SONIC_TRG
PA8.Signal=GPIO_Output
PA9.Signal=S_TIM1_CH2
PB6.Signal=USART1_TX
PB7.Signal=I2C1_SDA
PB8.Signal=I2C1_SCL
PB9.GPIO_Label=LASER_DISTANCE_XSHUT
PB9.Signal=GPIO_Output
PC0.GPIO_Label=DHT11
PC0.Signal=GPIO_Output
PC1.GPIO_Label=LOAD_CELL_DT
PC1.Signal=GPIO_Output
PC2.Signal=ADCx_IN3
PC3.GPIO_Label=LOAD_CELL_CLK
PC3.Signal=GPIO_Output

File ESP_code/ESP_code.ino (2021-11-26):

#include "Arduino.h"
#include "string.h"
#include <WiFi.h>
#include <HTTPClient.h>
#include <ArduinoJson.h>
#include "Adafruit_TCS34725.h"
#include "Wire.h"

//WiFi server
WiFiServer server(80);

//JSON documnets
StaticJsonDocument<512> doc;
StaticJsonDocument<512> doc_second;

// deviceId
uint8_t deviceId = 1;

// uveghaz id
String greenHouseId = "614f2d80351480b67fb8612d";

// rgb sensor piros
uint16_t colorRed = 0;

// rgb sensor zold
uint16_t colorGreen = 0;

// rgb sensor kek
uint16_t colorBlue = 0;

//Wifi server-re erkezett request
String header;

//Wifi halozat ssid
const char* ssid = "TEK megfigyelo allomas";

//Wifi halozat jelszo
const char* password = "0000000000";

//API vegpont eleresenek a "tove"
String apiRoute = "http://172.16.16.112:3000/api";

//Az UART-on keresztul kapott adat az STM mikrovezerlotol
String recivedDataFromSTM;

//RGB sensor
Adafruit_TCS34725 tcs = Adafruit_TCS34725(TCS34725_INTEGRATIONTIME_614MS, TCS34725_GAIN_1X);

//Csatlakozas a Wifi halozatra a megadott ssid es jelsza alapjan
void connectToWifiNetwork() {
  IPAddress local_IP(172, 16, 15, 46);
  IPAddress gateway(172, 16, 254, 254);
  IPAddress subnet(255, 255, 0, 0);
  WiFi.config(local_IP, gateway, subnet);

  WiFi.begin(ssid, password);
  Serial.print("Connecting to ");
  Serial.println(ssid);
  while(WiFi.status() != WL_CONNECTED) {
    delay(500);
    Serial.print(".");
  }
  Serial.print("\n Connected to WiFi network with IP Address: ");
  Serial.println(WiFi.localIP());
  server.begin();
}

//API GET hivas
String HTTPGetRequest(String additionalAPIRoute="null"){
   HTTPClient http;

   String payload = "";
   String apiRouteForRequest = apiRoute;
   //Ha erkezik parameterbe tovabbi route, akkor azt fuzzuk hozza
   if(additionalAPIRoute != "null")
   {
     apiRouteForRequest = apiRoute + additionalAPIRoute; 
   }

   Serial.println("ROUTE");
   Serial.println(apiRouteForRequest);
   http.begin(apiRouteForRequest);
   int httpResponseCode = http.GET();
   if (httpResponseCode>0)
   {
       Serial.print("HTTP Response code: ");
       Serial.println(httpResponseCode);
       payload = http.getString();
       Serial.println("PAYLOAD");
       Serial.println(payload);
   }
   else
   {
     Serial.print("Error code: ");
     Serial.println(httpResponseCode);
   }
   
   http.end();

   return payload;
}

//HTTP Post data
void HTTPPostData() {
  HTTPClient http;
  http.begin(apiRoute + "/device/measuredData");
  http.addHeader("Content-Type", "application/json");
  Serial.println(recivedDataFromSTM);
  http.POST(recivedDataFromSTM);
  http.end();
}

// RGB sensor ertek beolvasas
void measureColor() {
  uint16_t c;
  tcs.getRawData(&colorRed, &colorGreen, &colorBlue, &c);
}

//Inicializalas
void setup() {
  Serial.begin(115200);
  Serial2.begin(115200, SERIAL_8N1, 16, 17);
  connectToWifiNetwork();
  Wire1.begin(21, 22);
  
  if(tcs.begin(0x29, &Wire1))
  {
    Serial.println("Found sensor");
  } else {
    Serial.println("No sensor");
    while(1);
  }
}

void loop() {
  // API felol erkezett keresek kezelese
  WiFiClient client = server.available();
  if (client && client.available()) {
    while (client.connected()){
      char c = client.read();
      header += c;
      if (header.indexOf("GET /measure HTTP/1.1") >= 0) {
        Serial.println("START");
        char startChar[2] = {'0', '0'};
        Serial2.write(startChar);
        client.println("HTTP/1.1 200 OK");
        client.println("Content-type:text/html");
        client.println("Connection: close");
        client.println();
        header = "";
        client.stop();
      } 
      else if (header.indexOf("GET /config HTTP/1.1") >= 0)
      {
        String config = HTTPGetRequest("/config/deviceGetData?greenHouseId=" + greenHouseId + "&deviceId=" + deviceId);
        Serial.println("CONFIG");
        Serial.print(config);
        
        deserializeJson(doc_second, config);
        char configChar[2];
        int samplingTime = doc_second["config"];
        sprintf(configChar,"%d", samplingTime);
        Serial.println(configChar);
        Serial2.write(configChar);
        client.println("HTTP/1.1 200 OK");
        client.println("Content-type:text/html");
        client.println("Connection: close");
        client.println();
        header = "";
        client.stop();
      }
    }
  }
  
  if (Serial2.available() > 0) {
    recivedDataFromSTM = Serial2.readString();
    Serial.println(recivedDataFromSTM);

    // Ha 'S' karakter erkezik, akkor az a measurement_time inicializalas indulaskor
    if (recivedDataFromSTM[0] == 'S') 
    {
      String config = HTTPGetRequest("/config/deviceGetData?greenHouseId=" + greenHouseId + "&deviceId=" + deviceId);
        Serial.println("CONFIG");
        Serial.print(config);
        
        deserializeJson(doc_second, config);
        char configChar[2];
        int samplingTime = doc_second["config"];
        sprintf(configChar,"%d", samplingTime);
        Serial.println(configChar);
        Serial2.write(configChar);
        client.println("HTTP/1.1 200 OK");
        client.println("Content-type:tex  t/html");
        client.println("Connection: close");
        client.println();
        header = "";
        client.stop();
    } 
    else
    {
      measureColor();
      deserializeJson(doc, recivedDataFromSTM);
      doc["deviceId"] = deviceId;
      doc["greenHouseId"] = greenHouseId;
      doc["colorRed"] = colorRed;
      doc["colorGreen"] = colorGreen;
      doc["colorBlue"] = colorBlue;
      recivedDataFromSTM="";
      serializeJson(doc, recivedDataFromSTM);
      HTTPPostData();
    }
    Serial.println(recivedDataFromSTM);
  }
}

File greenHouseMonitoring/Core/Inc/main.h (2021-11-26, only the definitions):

#define DHT11_Pin GPIO_PIN_0
#define DHT11_GPIO_Port GPIOC
#define LOAD_CELL_DT_Pin GPIO_PIN_1
#define LOAD_CELL_DT_GPIO_Port GPIOC
#define LOAD_CELL_CLK_Pin GPIO_PIN_3
#define LOAD_CELL_CLK_GPIO_Port GPIOC
#define ULTRA_SONIC_TRG_Pin GPIO_PIN_8
#define ULTRA_SONIC_TRG_GPIO_Port GPIOA
#define LASER_DISTANCE_XSHUT_Pin GPIO_PIN_9
#define LASER_DISTANCE_XSHUT_GPIO_Port GPIOB

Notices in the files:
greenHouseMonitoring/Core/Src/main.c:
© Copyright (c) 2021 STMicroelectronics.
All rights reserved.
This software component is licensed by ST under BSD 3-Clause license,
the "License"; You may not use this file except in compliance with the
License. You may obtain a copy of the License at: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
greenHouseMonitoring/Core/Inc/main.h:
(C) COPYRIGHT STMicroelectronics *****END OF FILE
